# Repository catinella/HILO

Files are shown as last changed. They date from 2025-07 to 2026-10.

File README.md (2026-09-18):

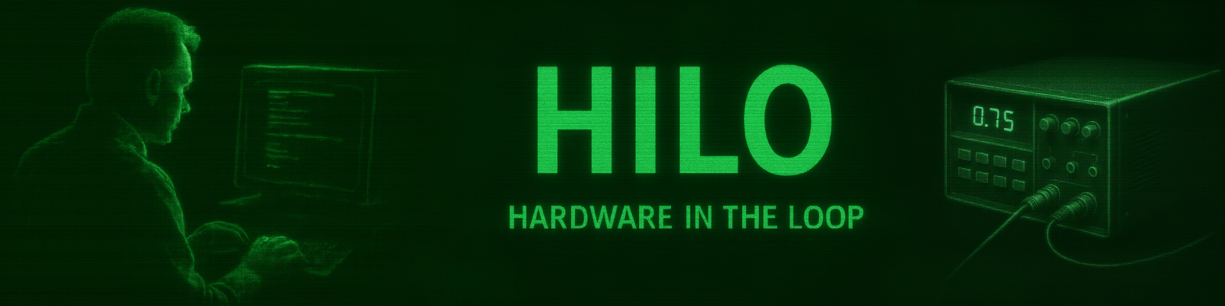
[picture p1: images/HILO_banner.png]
Project's banner


## 1.0 Files

|  Files/Dirs  | Description |
|---|---|
| firmware | The firmware for manager MCU |
| PCB | All the PCBs used in the project |
| console | The software used to manage the HILO  |
| images | Images and diagrams used by README.md |
| lgpl-3.0.txt | L-GPL ver 3.0 license document |

## 2.0 Decription
The goal of this project is to get a device that allows the user to test an electronic system in an easy way, also remotely.
In the 1990 when I was studying at high scool, who was developing new devices, used generic boxes with buttons, switches,
LEDs, displays.... installed on it. This device allowed him to emulate the external environment.

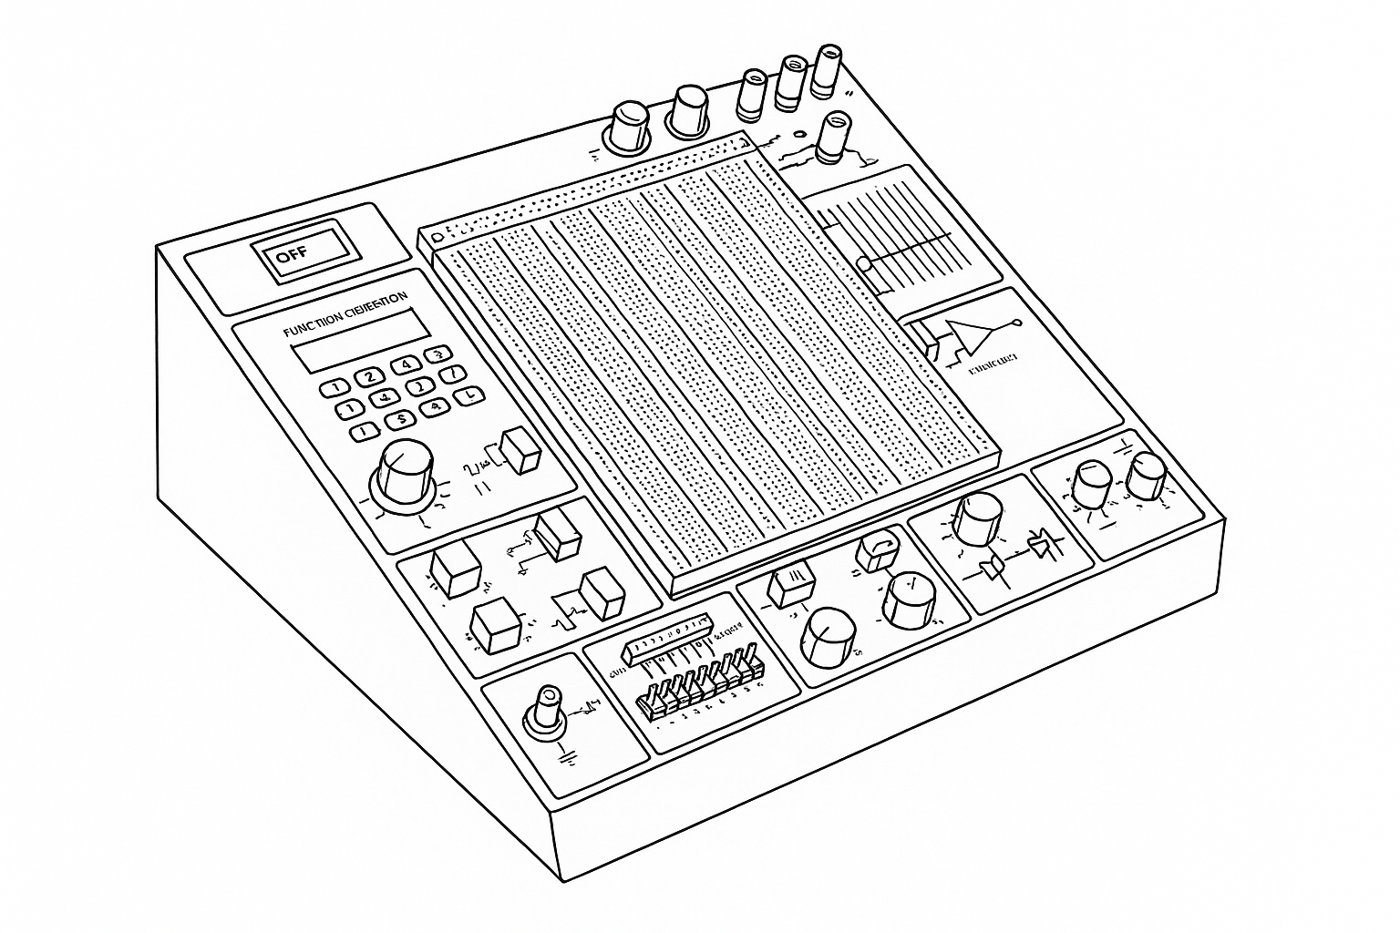
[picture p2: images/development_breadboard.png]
Testing device


It could look like useful for hobbyist, but it is an expensive, big, uncomfortable device, usually. 
For professional using it is not an adequate solution, because td does not allow you to see what happens in very short
time slots. For example, you need to monitor a 8bit bus behaviour after one millisecond after some digital input signal.
In this case, this kind of devices is absolutely unuseful.
Unfortunately, many Italian companies still use the same deplorable methodology, today too! Their test plans do not respect
the [V-model](https://www.sei.cmu.edu/blog/using-v-models-for-testing), and their firmware developers have to work on-site
only.

But the smarter companies use advanced and complicated devices that allow them to test their electronic products remotely,
in deeper and easier way. These tools are very sophisticated and programmable simulator, where they can simulate the
external environment in realistic and reliable way. These tools' class is called 
[**HILO**](https://en.wikipedia.org/wiki/Hardware-in-the-loop_simulation) (Hardware In the LOop).

This project aims to provide a low-cost and very very simple HILO. This one offers less and more limited features,
obviously.
	
#### 2.1 Test mode vs interactive mode
This HILO has two operating modes, that the user can set using the tester client GUI. In the first one (test-mode), the
user can monitor the DUT behavior for output-pins activities that run fast or for a short time periods. In the second one
the user can change the HILO's output-pins, directly, and verifies the DUT's behavior as consequence.

- **Test mode:**
	the user has to create a DUT test-recepit where he has to define the HILO's output-pins values, when they change during
	the test, and the max frequency of the changes. This synchronization will be also used to read the HILO's input-pins.
	Before to start the test, the HILO will convert the pin-status changes definitions in a scheduled output data sequence.
	When this raw-data sequence is ready, a bit configuration will be sent to the output-pins on every chock pulse, and
	the input pins will be read.

- **Interactive mode:**
	In this mode, the user will be able to change the HILO's output-pins values and check for the input ones status, 
	interactively. It is a good way to get an overview on the DUT's behavior, but, because you cannot schedule the
	changes with a precise time, it is not adequate for real-time interactions.

#### 2.3 Communication channel
In order to get a very fast, relayable, and flexible communication channel between the test-client software and the HILO's interface,
TCP/IP limk has been selected. In fact, it allows a huge transfer rate, a very high quality error checking and retransmission, and
virtually-infinite distances. It allows the test operator to work remotely respect to the HILO device, and the DUT, bviousely.
In order to make the HILO device using as comfotable as possible, WiFI connection has been selected. In this way the test operator
can set its own test-desk without to take care of boring cables to connect to it.

#### 2.4 Functional scheme overview:

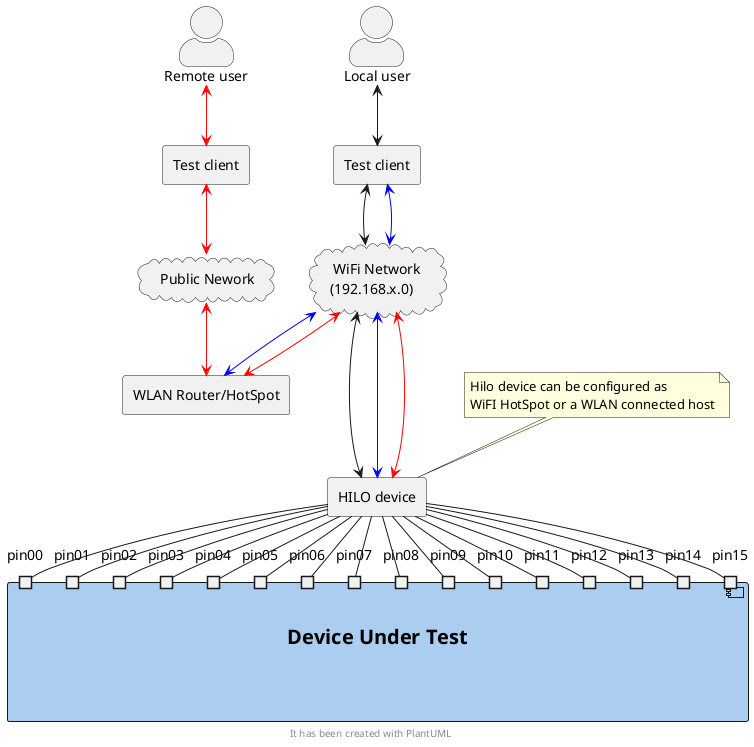
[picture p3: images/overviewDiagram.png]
overview_diagram
 

#### 2.5 Licence:
This project is a free software; you can redistribute it and/or modify it under the terms	of the GNU Lesser General Public License
as published by the Free Software Foundation; either version 3.0 of the License, or (at your option) any later version. 

For further details please read the full [LGPL text file](https://www.gnu.org/licenses/lgpl-3.0.txt).
You should find a copy of the GNU General Public License document in the root folder of the project; if not, write to the 

	Free Software Foundation, Inc.,
	59 Temple Place, Suite 330,
	Boston, MA  02111-1307  USA

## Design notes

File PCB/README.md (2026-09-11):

Project's banner

## 1.0 Files

| Files/Dirs | Description |
|---|---|
| kicadCustomComponents | The KiCAD libraries for the customized symbols/footprints |
| IOlinesManagement | The digital I/O lines interface |
| ElectricProtections | I/O Interface electric protection devices |
| MasterControlUnit | The HILO's brain |

## 2.0 Decription
By the hardware points of view, this HILO is composed by the following separated modules. Everyone of them is connected to
the master one using pin-headers connectors and flat-cables.

- The Master Conroller unit interface the I/O lines with the PC and perform the configured tests
- Digital I/O lines interface
- Output lines electrical protection
- (optional) Dedicated to the Analog lines PCB

## 2.1 Components documentation:
- [APS6404L-3SQR-SN](https://eu.mouser.com/datasheet/3/4815/1/APM_PSRAM_E3_QSPI%20(APS6404L-SQH%20KGD_PKG)%20v4.1.pdf)
- [ESP32 WROOM-32-UE](https://www.espressif.com/sites/default/files/documentation/esp32-wroom-32e_esp32-wroom-32ue_datasheet_en.pdf)
- [ESP32-DevKitC-V4](https://docs.espressif.com/projects/esp-idf/en/release-v4.2/esp32/hw-reference/esp32/get-started-devkitc.html)
- [STM32F407VG](https://www.st.com/resource/en/datasheet/dm00037051.pdf)
- [STM32F407G-DISC1](https://www.st.com/resource/en/data_brief/stm32f4discovery.pdf)

## 2.2 Logic scheme:
Overview Scheme

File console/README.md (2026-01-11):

Project's banner

## 1.0 Files

| Files/Dirs | Description |
|---|---|
| build.pro | QMake rules to build the whole project files |
| [conf.pri] | Building process configuration file |
| envVarOverriding.pri | QMake tool to get config data fron environment vars |
| gdbToConfig.pri | Qmake tool to set debug mode flags |
| utils.pri | QMake general purpose functions library |
| inputDevs | Virtual input devices (DUT point of view) |
| mainApp | The graphic console application |
| outputDevs | Virtual output devices |
| sharedComps | Graphic components used by the other modules |

## 2.0 Description
This folder hosts the HILO's GUI. When you use this HILO in interactive mode, this graphical interface will allow you to set your
test environment with many virtual tools (buttons, led-stripes, switches, keypads, displays... and so on) and verify the DUT's
behavior controlling its input and output in all configurations you have planned.

### 2.1 QT
In order to provide a multiplatform and very flexible GUI I have developed this module using the QT framework. In fact, QT allows
me to modify and create new widgets in a very powerful way.

## 3.0 code building
To provide a multiplaform building chain, I have used the official QT's tool **QMake6**. It requires a configuration file
file.pro) to produce the platform dependent build-chain files (eg. Makefile for Unix/Linux). After you obtained those files , you
can compile the code with your usual tool-chain, directly. For example, to performs the described tasks together, if you are using
a POSIX systems, you can run the following command:

	qmake6 *.pro && make all

[!] Use this approach for all sub-modules' tests too.

## 4.0 How to write new I/O virtual devices

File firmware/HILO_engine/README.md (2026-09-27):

Project's banner

## 1.0 Files

| **Files and dirs** | **Description** |
|---|---|
| build |  The rules you need to compile the project |
| Core |  The project's source code |
| Drivers |  The drivers's source code |
| HILO_engine.ioc | |
| STM32F031K6TX_FLASH.ld |  The linker script generated by CubeMX |

## 2.0 Description

This component is the one that performs the test, effectively.
Please, read the ../README and ../HILO_interface/README files

### 2.1 Firmware's main steps

0) Hardware initialization
   Subsystems initialization and I2C channel opening in slave-mode
		
1) MCU waiting for a command by the HILO_interface component

2) Scheduled test
   if **HENG_TEST_START** command is received and the test has been previously properly configured, then the MCU starts
   to perform the test and stores the results in the SRAM. While this process is running, the MCU can reply to the
   **HENG_TEST_GETSTATUS** request, sending the number of the last executed step. At the end of the test or if an 
   **HENG_TEST_STOP** message is received, the MCU returns to wait for new commands.
		
3) Interactive test
   Before to perform the test, the MCU has to get an **HENG_RT_SETPINSDIR** message to configure the I/O type of its pins.
   When the **HENG_RT_START** command is received, the MCU reads data from its input pins and returns the data to the
   Hilo_interfaces via SPI.
   The user will be able to change the output pins' values with the **HENG_RT_SETPINSVAL** command, in "realtime".
   The **HENG_RT_STOP** command will force the MCU to returns at the initial state.

### 2.2 SRAM

This external memory is used just in the scheduled-test mode. 
In order to achieve better speed performance, the MCU uses two different memory areas, one just for reading operations the other
just for data writing, and they are also connected with two different SPI ports.
For every test's step, MCU will perform the following steps:

1) The output pins configuration will be read from the first memory area
2) HILO's pins will be set properly
3) The HILO's input pins value will be stored in the second memory area.
4) The internal counter will be incremented

Output-pins' configurations layout
		
| Test step | Bits mask (0=IN)  | OUT pins value  |
|---|---|---|
| **step 1**| XXXXXXXX:XXXXXXXX | XXXXXXXX:XXXXXXXX |
| **step 2**| XXXXXXXX:XXXXXXXX | XXXXXXXX:XXXXXXXX |
| **step 3**| XXXXXXXX:XXXXXXXX | XXXXXXXX:XXXXXXXX |
| **step n**|///////////////////|///////////////////|

Test results (8 Bytes) record: digital and analog input-pins values

| Test step  | Inputs pins | Fuses status | Data from A/D |  Not used  |
|---|---|---|---|---|
| **step 0** | 2 bytes | 2 bytes | 2 Bytes |  2 bytes |
| **step 1** | 2 bytes | 2 bytes | 2 Bytes |  2 bytes |
| **step 2** | 2 bytes | 2 bytes | 2 Bytes |  2 bytes |
| **step n** |/////////////|//////////////|///////////////|////////////|

### 2.3 Dynamic I/O configuration

Each test step is encoded using 4 bytes:

- 2 bytes define the I/O direction of the test lines;
- 2 bytes define the values to be generated on the lines configured as outputs.

At first sight, storing the I/O direction for every test step may appear redundant, since in many tests the pin direction does
not change during the whole test sequence.

However, keeping the I/O configuration as part of each test step allows HILO to change the direction of any test line during
test execution. This is required to reproduce the behaviour of bidirectional and half-duplex interfaces.

A particularly relevant example is an open-drain line. In this case, HILO can generate the two logical line states as:

- **LOW:** configure the line as output and drive it low;
- **RELEASED:** configure the line as input, leaving the external pull-up free to drive it high.

Therefore, the I/O direction is not merely a static hardware configuration: it can be considered part of the test stimulus itself.

This flexibility has a cost, since the STM32F407 must potentially update the GPIO configuration at every test step. However, the
target test frequency is in the range of a few hundred kHz. At 500 kHz, for example, a complete test step lasts 2 µs, corresponding
to 336 CPU cycles with the STM32F407 running at 168 MHz.

The worst-case execution time of a test step must therefore satisfy:

`Tstep = TSRAM_read + TGPIO_config + TGPIO_write + TGPIO_read + TSRAM_write + Toverhead < Ttimer`

The actual execution time will be measured during implementation. If the complete operation fits within the required timer period with
sufficient margin, the additional per-step I/O configuration is considered an acceptable cost for the flexibility it provides.

## 3.0 Building procedure
	In order to keep track of every change, in the building rules too, I have chosen to use the usual Makefile building chain
	instead the ST proprietary one. So, in order to build the firmware use make command from the "build" folder inside

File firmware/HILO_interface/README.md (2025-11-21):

Project's banner

## 1.0 Files

| **Files and dirs** | **Description** |
|---|---|
| CMakeLists.txt | It contains the rules you need to build the firmware or the integration tests |
| components | All used by firmware libraries are stored in a sub-folder of this one |
| main | It contains the firmware and integration tests |
| [build] | Temporary folder used to buid the code |
| [CMakeLists.conf]  | Building process' configuration file |
| configUtils.cmake  | CMake functions library |
| sdkconfig | The ESP-IDF's configuration file |

## 2.0 Description
This component provides the HILO device's interface feature. As you can read in the diagram in the main README file, this interface
is used by the test client software, and accepts data/commands to configure, start, manage the test process.

### 2.1 Hardware considerations
The MCU used to implement the HILO's interface is the 
[ESP32 WROOM-32-UE](https://www.espressif.com/sites/default/files/documentation/esp32-wroom-32e_esp32-wroom-32ue_datasheet_en.pdf).
It is a cheap device but its characteristics allows it to perform all the required features, easily. The followings are the main
ones:
- 448 KB ROM
- 520 KB SRAM
- WiFI support (802.11 b/g/n (802.11n up to 150 Mbps))
- Integrated crystal (40MHz)
- External antennna
- SPI and I2c BUS support

#### 2.2 Communication protocol
in order to obtain the most standard communication protocol possible, which also implements sophisticated access protection
mechanisms, the REST API protocol has been used for all HILO device's external communication.
	
###### 2.2.1 REST APIs for scheduled-test mode:
| REST API |  Description |
|---|---|
| **POST** <HILO>/test/set_recepit  | The test's recipit will be accepted, converted, and stored in the SRAM |
| **POST** <HILO>/test/start | If a recepit has been accepted and converted then this command will start the test |
| **POST** <HILO>/test/stop | If a test is running then it will be stopped |
| **GET**  <HILO>/test/get_status | It returns the test status {IN_PROGRESS|COMPLETED|STOOPED} |
| **GET**  <HILO>/test/get_resuts | It returns all data produced by the last executed test |

###### 2.2.2 JSONs for scheduled-test mode:
	<HILO>/test/set_recepit = {
		configuration: {
			//
			// I/O direction configuration
			//
			pin0:  {IN|OUT}, 
			pin1:  {IN|OUT},
			...
			pin15: {IN|OUT},

			// Frequency in Khz
			freq:  <n>           // 1 = 0.1 Khz
		},
		test_outputData[] : {
			type:  fixedTimePeriod,
			pin:   <0-15>,
			value: {high|low|swap},
			start: <milliseconds>,
			stop:  <milliseconds>
		}, {
			type:      squareWave,
			pin:       <0-15>,
			period:    <milliseconds>,
			dutyCycle: <0-100>,          // percent
			start:     <milliseconds>,
			stop:      <milliseconds>
		}, {
			type:   number,
			pins[]: <0-15>, <0-15>, <0-15>, <0-15>, <0-15>, <0-15>, <0-15>, <0-15>  // 8bits MSB --> LSB
			period: <milliseconds>,
			start:  <milliseconds>,
			stop:   <milliseconds>
		}, ...
	}

###### 2.2.3 REST APIs for interactive test mode:
| REST API |  Description |
|---|---|
| **POST** <HILO>/intv/configure | It configures the bits direction ant the TCL's ip-address|
| **POST** <HILO>/intv/send_data | It force the HILO's output pins to change their status |
| **GET**  <HILO>/intv/get_fuses | It returns the status of the fuses |

###### 2.2.4 JSONs for interactive-test mode:
	<HILO>/intv/configure = {
		pindir = <16bit hex-number>   // 0 = input; 1 = output
		streamaddr = <test-client ip-addr:socket>
	}
	<HILO>/intv/send_data = <16bit hex-number>

#### 2.3 SRAM content
The SRAMs are used just in scheduled-test-mode. This modality is based on a test-recipit composed by all the I/O changes and
the time of their performing, mainly. This data is translated by the HILO-interface into an IO-pins configurations sequence,
one for every time time period. Then the sequence is written into one of the two SRAM banks.

#### 2.4 Communication with HILO-engine
In order to exchange adata between the interface and the engine, they uses two different communication data buses. The first one
is used by the interface to send commands, and because it does not need to be very fast, the 12C bus has been selected for this
purpose. The second bus is used by the engine's MCU to send the input-pins data to the interface, and to allow fast data
transmission rating, the SPI bus has been selected.

###### 2.4.1 HILO-engine accepted commands in scheduled-test mode:

| **8bit numeric ID** | **Descriprion** |
|---|---|
| HENG_TEST_START | bla bla bla |
| HENG_TEST_STOP | bla bla bla |
| HENG_TEST_GETSTATUS | bla bla bla |
		 
###### 2.4.2 HILO-engine accepted commands in interactive mode:

|  **8bit numeric ID**  | **Data field** |  **Descriprion** |
|---|---|---|
| HENG_INTV_START | N/A | |
| HENG_INTV_STOP | N/A | |
| HENG_INTV_SETPINSDIR  |  \<pins-dir> | |
| HENG_INTV_SETPINSVAL  | \<pins-value>  | |

## 3.0 Buiding procedure
In order to build the code for ESP32 that belongs to this module, you need the
[ESP-IDS (5.4.x)](https://docs.espressif.com/projects/esp-idf/en/v5.4.2/esp32/get-started/index.html.) software framework.
Please, read the documentation to get the right procedure to build the code.

This firmware source code tree contains unit-tests and integration tests too. The **unit-tests** cover the components' code, not the
main. To build these tests find the "test" folder into the proper component home (component/\<component-name>) and follow the
instructions decribed in the README or Makefile file storeed in tht path. 
To execute the **integration tests**, you need to build the test for the target and also upload the test-firmware into the target. So,
in order to select wich firmware (test<n>.c, ...prod.c) you want to use you have to set the Makefike.conf file properly.
For further information, please, read the documentation section in the CMakeLists.txt file.

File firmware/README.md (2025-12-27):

Project's banner

## 1.0 Files

| **Files and dirs** | **Description** |
|---|---|
| HILO_engine | The real-time component that performs the scheduled test |
| HILO_interface | The component that interface the HILO's engine with the test client system |

## 2.0 Description
In oder to get a more comfortable and an high performave instrument, the HILO device uses more MCUs.
This folder contains the firmwares for all used MCUs.
	
### 2.1 Dataflow description:
Please, consider the logic scheme stored in the ../PCB/README file.
The HILO can function in two different ways: **scheduled-mode** and **interactive-mode**.

- In the first one, the user have to prepare a test's recipit and send it via REST API to the HILO_interface component.
Then it will instructs the HILO_engine on the step iw will have to follow to perform the test correctly. At the end of
the test, the software-client will retrive all resulted data, and the user will be able to evaluate the the DUT's
behaviohr.
	
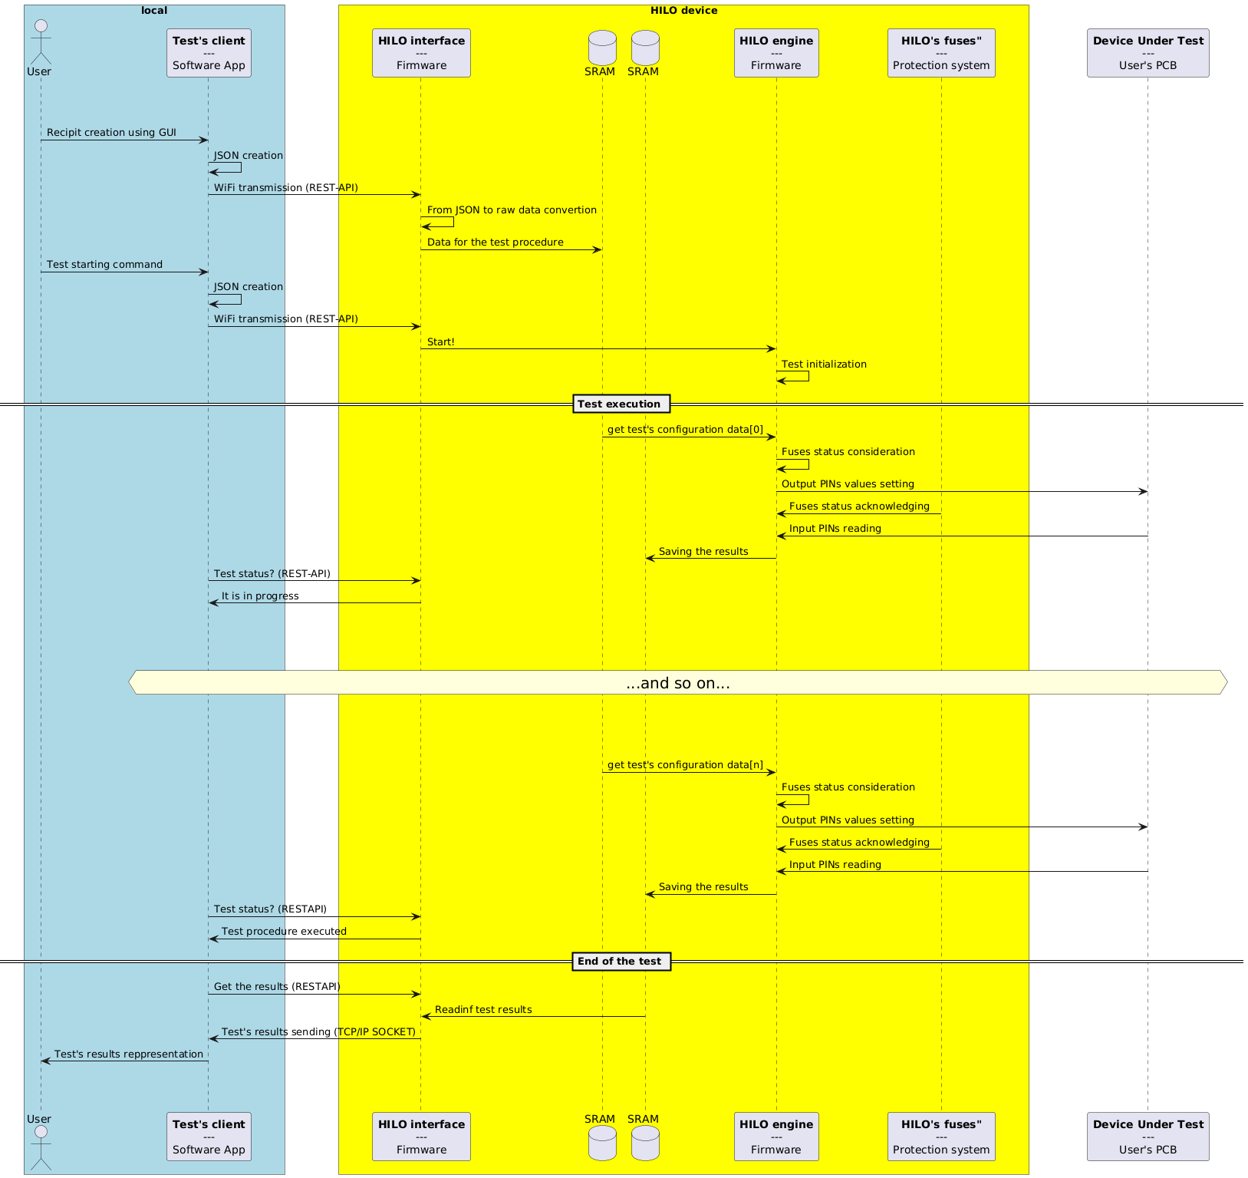
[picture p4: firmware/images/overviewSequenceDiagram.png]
Time sequence diagram for the **scheduled mode**


- In the interactive-mode, the user can change the output-pins value via REST API, dinamically. All data on the monitored
input pins will be continuously reported via TCP/IP stream. So, the user will be able to evaluate the DUT behavior
modifying the DUT's input and checking for the DUT's output, dinamically. Because the DUT's inputs change manually, the
HILO's sample rating is set to 1Khz.

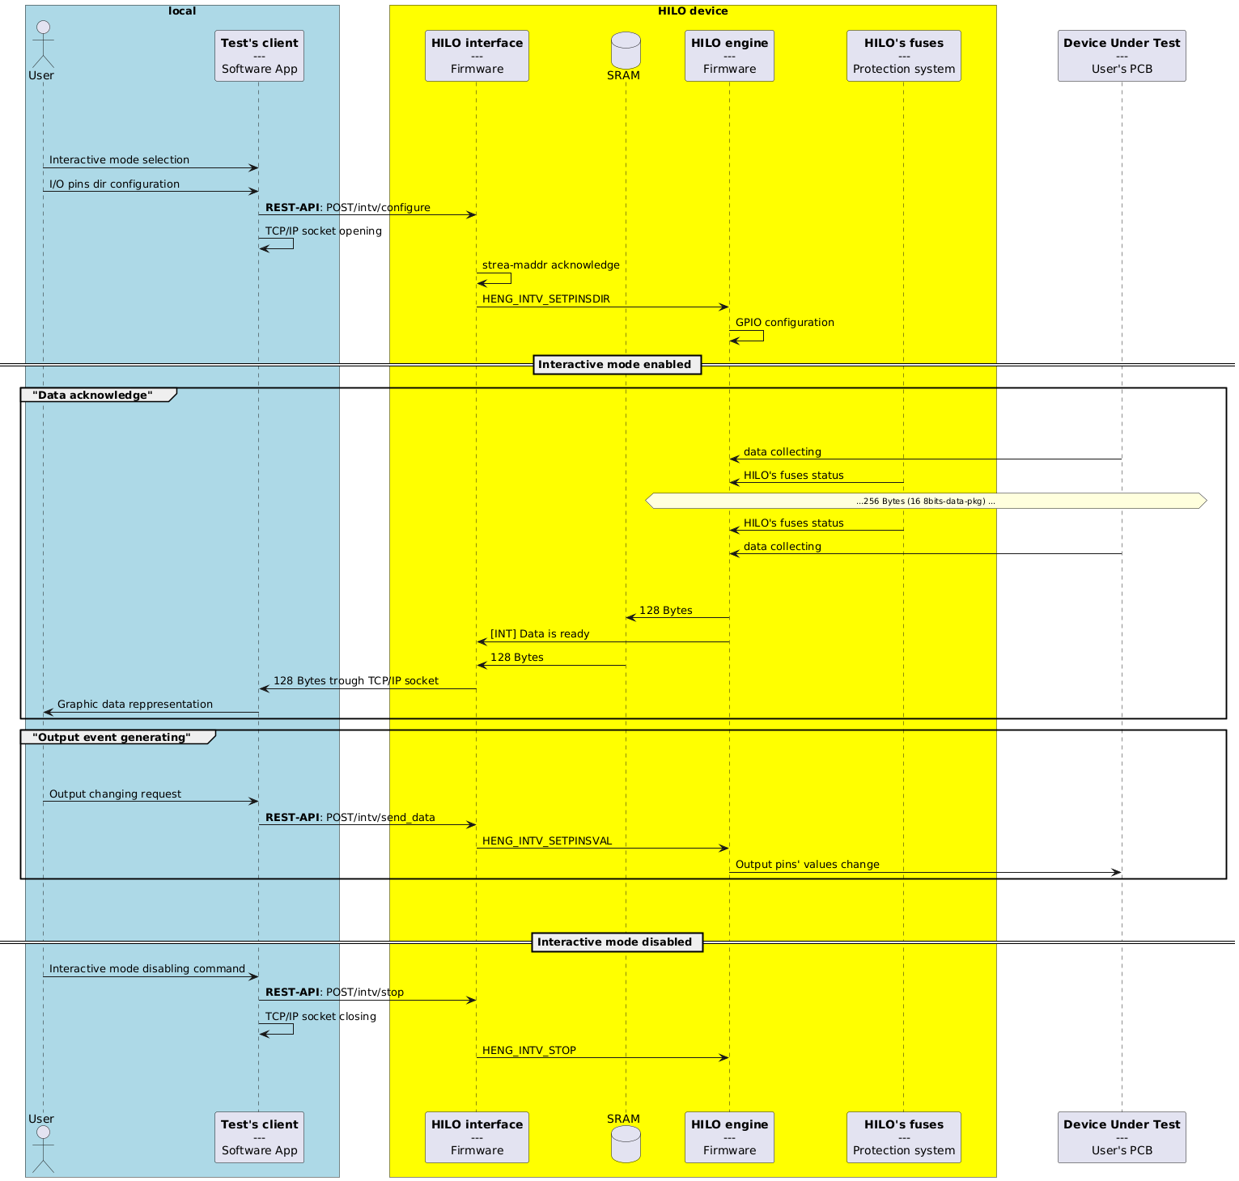
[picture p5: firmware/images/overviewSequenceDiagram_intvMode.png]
Time sequence diagram for the **interactive mode**


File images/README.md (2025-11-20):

Project's banner

## 1.0 Files

| Files and Directories | Description |
|---|---|
|development_breadboard.png | Image used in the main README.md file |
|HILO_banner.png | The title of every README.md file |
|Makefile | Automation tool for diagram generating  |
|[Makefile.conf] | Optional Makefile's configuration file  |
|overviewDiagram.puml | Diagram used in the main README.md file |
|overviewDiagram.png | Generated image |

## 2.0 Decription
In order to provide README files where they are more comfortable to read, I choice to use Markup-Down (MD) language instead row
ASCII text. This type of README files are more compatible with GITHUB and the MD language has become an appreciated standart for
the documentation files. 

One of the more appreciated MD's feature is the possibility to embedd images, diagrams, links... into the document. But in order
to keepm an ordered tree, I choise to store all images in this folder.

## 2.1 Diagram generating
In order to include the diagram's file in the project's file versioning I use the [plantuml](https://plantuml.com) app. It allows
me to create complicated graphic diagrams starting by a sequence of ASCII instructions. The 
[offical manual](https://plantuml.com/guide#goog_rewarded) is also available.

## 2.2 Images on GIT??!!!??
I know, many people are drawing a terrible expressions in their face, now! GIT is not made to store images. I completely
agree with you. My solution would be to include puml file only in git, and store all static images in a web-area. Unfortunately
GITHB does not provide a web-space!! Someone use a proper branch for the image files. But it looks like Walt Disney's catoon
Pippo (Goofy in EN) when he sweep the dust under the carpet, IMHO. So, I have to wait that GitHUB implements a PlantUML engine in
its Markdown language interpreter.

However, I will be happy to evaluate every possible suggestion

A sentence by ChatGPT-5.1 about PlantUML: "___Il futuro si sta allineando a PlantUML, non il contrario.___"; translated version
"___So the future is aligning with PlantUML, not the other way around.___"
by ChatGPT (20/11/2025)

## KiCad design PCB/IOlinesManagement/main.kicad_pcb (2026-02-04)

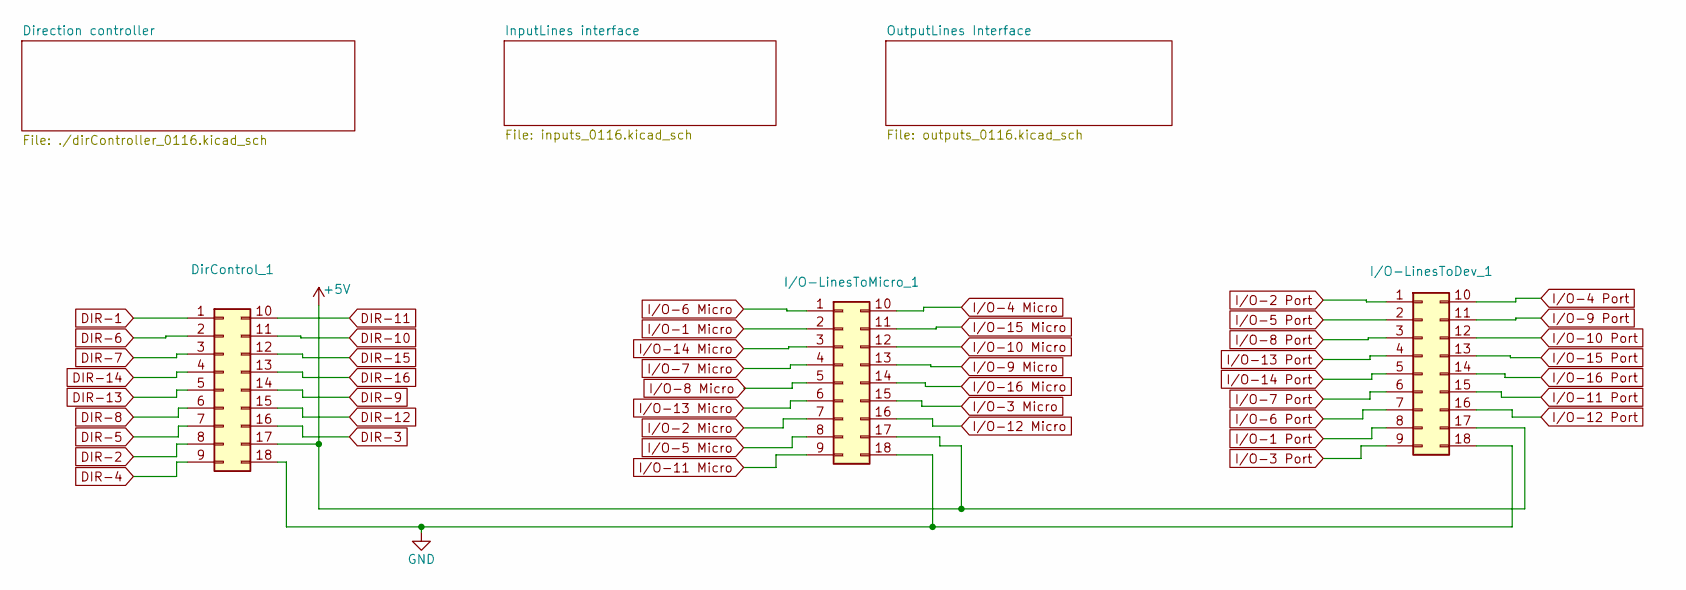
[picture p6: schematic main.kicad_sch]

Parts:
DirControl_1: Conn_02x09_Top_Bottom; PinHeader_2x09_P2.54mm_Vertical
I/O-LinesToDev_1: Conn_02x09_Top_Bottom; PinHeader_2x09_P2.54mm_Vertical
I/O-LinesToMicro_1: Conn_02x09_Top_Bottom; PinHeader_2x09_P2.54mm_Vertical

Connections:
+5V: DirControl_1.17, I/O-LinesToDev_1.17, I/O-LinesToMicro_1.17; also elsewhere on the board
DIR-1: DirControl_1.1; also elsewhere on the board
DIR-2: DirControl_1.8; also elsewhere on the board
DIR-3: DirControl_1.16; also elsewhere on the board
DIR-4: DirControl_1.9; also elsewhere on the board
DIR-5: DirControl_1.7; also elsewhere on the board
DIR-6: DirControl_1.2; also elsewhere on the board
DIR-7: DirControl_1.3; also elsewhere on the board
DIR-8: DirControl_1.6; also elsewhere on the board
DIR-9: DirControl_1.14; also elsewhere on the board
DIR-10: DirControl_1.11; also elsewhere on the board
DIR-11: DirControl_1.10; also elsewhere on the board
DIR-12: DirControl_1.15; also elsewhere on the board
DIR-13: DirControl_1.5; also elsewhere on the board
DIR-14: DirControl_1.4; also elsewhere on the board
DIR-15: DirControl_1.12; also elsewhere on the board
DIR-16: DirControl_1.13; also elsewhere on the board
GND: DirControl_1.18, I/O-LinesToDev_1.18, I/O-LinesToMicro_1.18; also elsewhere on the board
I/O-1 Micro: I/O-LinesToMicro_1.2; also elsewhere on the board
I/O-1 Port: I/O-LinesToDev_1.8; also elsewhere on the board
I/O-2 Micro: I/O-LinesToMicro_1.7; also elsewhere on the board
I/O-2 Port: I/O-LinesToDev_1.1; also elsewhere on the board
I/O-3 Micro: I/O-LinesToMicro_1.15; also elsewhere on the board
I/O-3 Port: I/O-LinesToDev_1.9; also elsewhere on the board
I/O-4 Micro: I/O-LinesToMicro_1.10; also elsewhere on the board
I/O-4 Port: I/O-LinesToDev_1.10; also elsewhere on the board
I/O-5 Micro: I/O-LinesToMicro_1.8; also elsewhere on the board
I/O-5 Port: I/O-LinesToDev_1.2; also elsewhere on the board
I/O-6 Micro: I/O-LinesToMicro_1.1; also elsewhere on the board
I/O-6 Port: I/O-LinesToDev_1.7; also elsewhere on the board
I/O-7 Micro: I/O-LinesToMicro_1.4; also elsewhere on the board
I/O-7 Port: I/O-LinesToDev_1.6; also elsewhere on the board
I/O-8 Micro: I/O-LinesToMicro_1.5; also elsewhere on the board
I/O-8 Port: I/O-LinesToDev_1.3; also elsewhere on the board
I/O-9 Micro: I/O-LinesToMicro_1.13; also elsewhere on the board
I/O-9 Port: I/O-LinesToDev_1.11; also elsewhere on the board
I/O-10 Micro: I/O-LinesToMicro_1.12; also elsewhere on the board
I/O-10 Port: I/O-LinesToDev_1.12; also elsewhere on the board
I/O-11 Micro: I/O-LinesToMicro_1.9; also elsewhere on the board
I/O-11 Port: I/O-LinesToDev_1.15; also elsewhere on the board
I/O-12 Micro: I/O-LinesToMicro_1.16; also elsewhere on the board
I/O-12 Port: I/O-LinesToDev_1.16; also elsewhere on the board
I/O-13 Micro: I/O-LinesToMicro_1.6; also elsewhere on the board
I/O-13 Port: I/O-LinesToDev_1.4; also elsewhere on the board
I/O-14 Micro: I/O-LinesToMicro_1.3; also elsewhere on the board
I/O-14 Port: I/O-LinesToDev_1.5; also elsewhere on the board
I/O-15 Micro: I/O-LinesToMicro_1.11; also elsewhere on the board
I/O-15 Port: I/O-LinesToDev_1.13; also elsewhere on the board
I/O-16 Micro: I/O-LinesToMicro_1.14; also elsewhere on the board
I/O-16 Port: I/O-LinesToDev_1.14; also elsewhere on the board

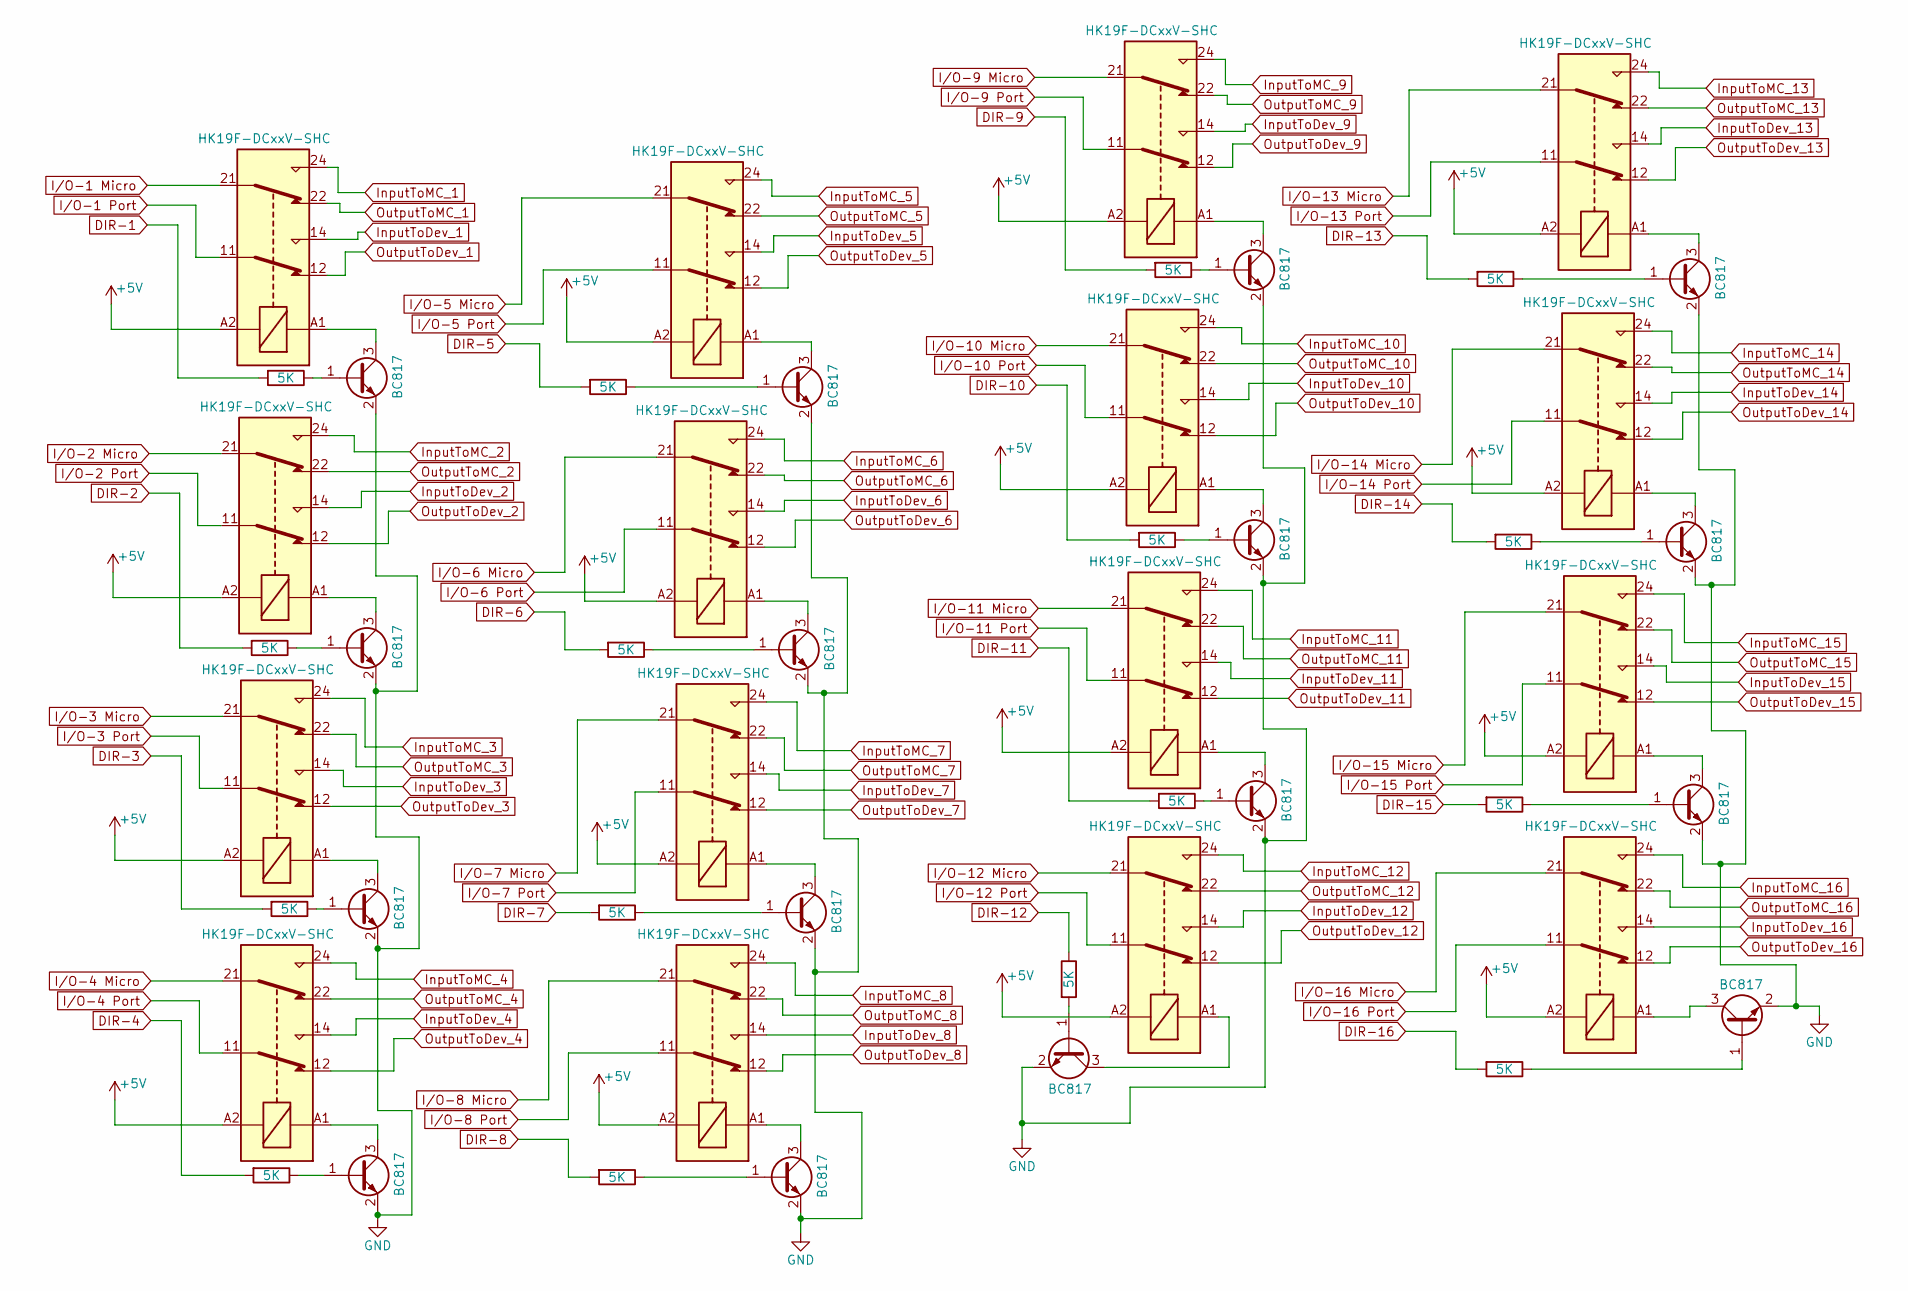
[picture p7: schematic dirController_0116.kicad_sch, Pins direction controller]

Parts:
K1, K2, K3, K4, K5, K6, K7, K8, K9, K10, K11, K12, K13, K14, K15, K16: HK19F-DCxxV-SHC; Relay_DPDT_Finder_30.22
Q1, Q2, Q3, Q4, Q5, Q6, Q7, Q8, Q9, Q10, Q11, Q12, Q13, Q14, Q15, Q16: BC817; SOT-23
R1, R2, R3, R4, R5, R6, R7, R8, R9, R10, R11, R12, R13, R14, R15, R16: 5K; R_1206_3216Metric

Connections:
+5V: K1.A2, K2.A2, K3.A2, K4.A2, K5.A2, K6.A2, K7.A2, K8.A2, K9.A2, K10.A2, K11.A2, K12.A2, K13.A2, K14.A2, K15.A2, K16.A2; also elsewhere on the board
DIR-1: R3.2; also elsewhere on the board
DIR-2: R1.2; also elsewhere on the board
DIR-3: R4.2; also elsewhere on the board
DIR-4: R2.2; also elsewhere on the board
DIR-5: R5.2; also elsewhere on the board
DIR-6: R8.2; also elsewhere on the board
DIR-7: R6.2; also elsewhere on the board
DIR-8: R7.2; also elsewhere on the board
DIR-9: R11.2; also elsewhere on the board
DIR-10: R10.2; also elsewhere on the board
DIR-11: R12.2; also elsewhere on the board
DIR-12: R9.1; also elsewhere on the board
DIR-13: R13.2; also elsewhere on the board
DIR-14: R16.2; also elsewhere on the board
DIR-15: R14.2; also elsewhere on the board
DIR-16: R15.2; also elsewhere on the board
GND: Q1.2 (E), Q2.2 (E), Q3.2 (E), Q4.2 (E), Q5.2 (E), Q6.2 (E), Q7.2 (E), Q8.2 (E), Q9.2 (E), Q10.2 (E), Q11.2 (E), Q12.2 (E), Q13.2 (E), Q14.2 (E), Q15.2 (E), Q16.2 (E); also elsewhere on the board
InputToDev_1: K1.14; also elsewhere on the board
InputToDev_2: K2.14; also elsewhere on the board
InputToDev_3: K3.14; also elsewhere on the board
InputToDev_4: K4.14; also elsewhere on the board
InputToDev_5: K5.14; also elsewhere on the board
InputToDev_6: K6.14; also elsewhere on the board
InputToDev_7: K7.14; also elsewhere on the board
InputToDev_8: K8.14; also elsewhere on the board
InputToDev_9: K9.14; also elsewhere on the board
InputToDev_10: K10.14; also elsewhere on the board
InputToDev_11: K11.14; also elsewhere on the board
InputToDev_12: K12.14; also elsewhere on the board
InputToDev_13: K13.14; also elsewhere on the board
InputToDev_14: K14.14; also elsewhere on the board
InputToDev_15: K15.14; also elsewhere on the board
InputToDev_16: K16.14; also elsewhere on the board
InputToMC_1: K1.24; also elsewhere on the board
InputToMC_2: K2.24; also elsewhere on the board
InputToMC_3: K3.24; also elsewhere on the board
InputToMC_4: K4.24; also elsewhere on the board
InputToMC_5: K5.24; also elsewhere on the board
InputToMC_6: K6.24; also elsewhere on the board
InputToMC_7: K7.24; also elsewhere on the board
InputToMC_8: K8.24; also elsewhere on the board
InputToMC_9: K9.24; also elsewhere on the board
InputToMC_10: K10.24; also elsewhere on the board
InputToMC_11: K11.24; also elsewhere on the board
InputToMC_12: K12.24; also elsewhere on the board
InputToMC_13: K13.24; also elsewhere on the board
InputToMC_14: K14.24; also elsewhere on the board
InputToMC_15: K15.24; also elsewhere on the board
InputToMC_16: K16.24; also elsewhere on the board
I/O-1 Micro: K1.21; also elsewhere on the board
I/O-1 Port: K1.11; also elsewhere on the board
I/O-2 Micro: K2.21; also elsewhere on the board
I/O-2 Port: K2.11; also elsewhere on the board
I/O-3 Micro: K3.21; also elsewhere on the board
I/O-3 Port: K3.11; also elsewhere on the board
I/O-4 Micro: K4.21; also elsewhere on the board
I/O-4 Port: K4.11; also elsewhere on the board
I/O-5 Micro: K5.21; also elsewhere on the board
I/O-5 Port: K5.11; also elsewhere on the board
I/O-6 Micro: K6.21; also elsewhere on the board
I/O-6 Port: K6.11; also elsewhere on the board
I/O-7 Micro: K7.21; also elsewhere on the board
I/O-7 Port: K7.11; also elsewhere on the board
I/O-8 Micro: K8.21; also elsewhere on the board
I/O-8 Port: K8.11; also elsewhere on the board
I/O-9 Micro: K9.21; also elsewhere on the board
I/O-9 Port: K9.11; also elsewhere on the board
I/O-10 Micro: K10.21; also elsewhere on the board
I/O-10 Port: K10.11; also elsewhere on the board
I/O-11 Micro: K11.21; also elsewhere on the board
I/O-11 Port: K11.11; also elsewhere on the board
I/O-12 Micro: K12.21; also elsewhere on the board
I/O-12 Port: K12.11; also elsewhere on the board
I/O-13 Micro: K13.21; also elsewhere on the board
I/O-13 Port: K13.11; also elsewhere on the board
I/O-14 Micro: K14.21; also elsewhere on the board
I/O-14 Port: K14.11; also elsewhere on the board
I/O-15 Micro: K15.21; also elsewhere on the board
I/O-15 Port: K15.11; also elsewhere on the board
I/O-16 Micro: K16.21; also elsewhere on the board
I/O-16 Port: K16.11; also elsewhere on the board
unnamed: Q1.1 (B), R3.1
unnamed: K1.A1, Q1.3 (C)
unnamed: Q2.1 (B), R1.1
unnamed: K2.A1, Q2.3 (C)
unnamed: Q3.1 (B), R4.1
unnamed: K3.A1, Q3.3 (C)
unnamed: Q4.1 (B), R2.1
unnamed: K4.A1, Q4.3 (C)
unnamed: Q5.1 (B), R7.1
unnamed: K8.A1, Q5.3 (C)
unnamed: Q6.1 (B), R8.1
unnamed: K6.A1, Q6.3 (C)
unnamed: Q7.1 (B), R5.1
unnamed: K5.A1, Q7.3 (C)
unnamed: Q8.1 (B), R6.1
unnamed: K7.A1, Q8.3 (C)
unnamed: Q9.1 (B), R9.2
unnamed: K12.A1, Q9.3 (C)
unnamed: Q10.1 (B), R11.1
unnamed: K9.A1, Q10.3 (C)
unnamed: Q11.1 (B), R10.1
unnamed: K10.A1, Q11.3 (C)
unnamed: Q12.1 (B), R12.1
unnamed: K11.A1, Q12.3 (C)
unnamed: Q13.1 (B), R16.1
unnamed: K14.A1, Q13.3 (C)
unnamed: Q14.1 (B), R13.1
unnamed: K13.A1, Q14.3 (C)
unnamed: Q15.1 (B), R14.1
unnamed: K15.A1, Q15.3 (C)
unnamed: Q16.1 (B), R15.1
unnamed: K16.A1, Q16.3 (C)
OutputToDev_1: K1.12; also elsewhere on the board
OutputToDev_2: K2.12; also elsewhere on the board
OutputToDev_3: K3.12; also elsewhere on the board
OutputToDev_4: K4.12; also elsewhere on the board
OutputToDev_5: K5.12; also elsewhere on the board
OutputToDev_6: K6.12; also elsewhere on the board
OutputToDev_7: K7.12; also elsewhere on the board
OutputToDev_8: K8.12; also elsewhere on the board
OutputToDev_9: K9.12; also elsewhere on the board
OutputToDev_10: K10.12; also elsewhere on the board
OutputToDev_11: K11.12; also elsewhere on the board
OutputToDev_12: K12.12; also elsewhere on the board
OutputToDev_13: K13.12; also elsewhere on the board
OutputToDev_14: K14.12; also elsewhere on the board
OutputToDev_15: K15.12; also elsewhere on the board
OutputToDev_16: K16.12; also elsewhere on the board
OutputToMC_1: K1.22; also elsewhere on the board
OutputToMC_2: K2.22; also elsewhere on the board
OutputToMC_3: K3.22; also elsewhere on the board
OutputToMC_4: K4.22; also elsewhere on the board
OutputToMC_5: K5.22; also elsewhere on the board
OutputToMC_6: K6.22; also elsewhere on the board
OutputToMC_7: K7.22; also elsewhere on the board
OutputToMC_8: K8.22; also elsewhere on the board
OutputToMC_9: K9.22; also elsewhere on the board
OutputToMC_10: K10.22; also elsewhere on the board
OutputToMC_11: K11.22; also elsewhere on the board
OutputToMC_12: K12.22; also elsewhere on the board
OutputToMC_13: K13.22; also elsewhere on the board
OutputToMC_14: K14.22; also elsewhere on the board
OutputToMC_15: K15.22; also elsewhere on the board
OutputToMC_16: K16.22; also elsewhere on the board

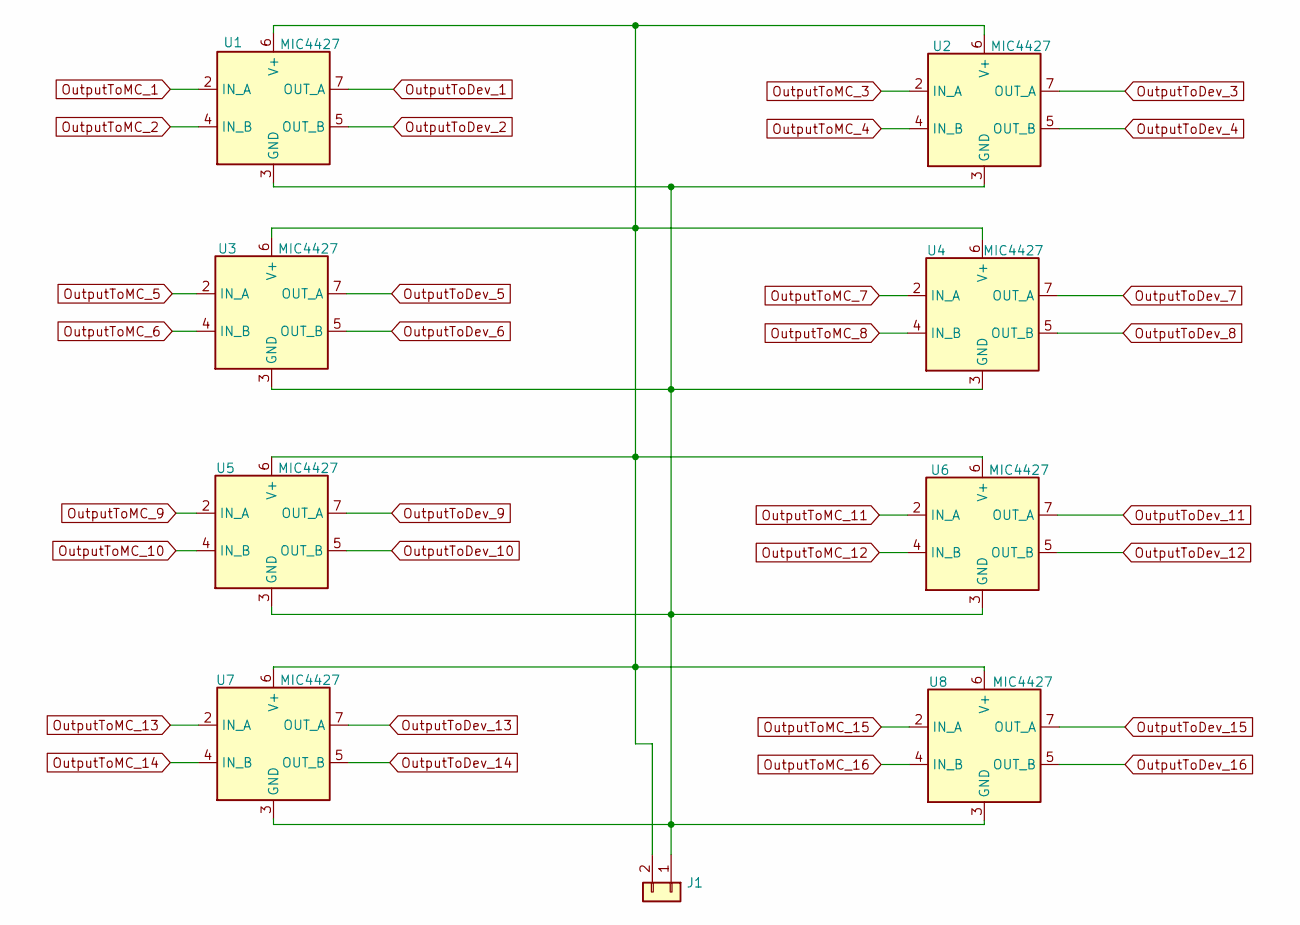
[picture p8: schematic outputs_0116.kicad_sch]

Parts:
J1: Conn_01x02; PinHeader_1x02_P2.54mm_Vertical
U1, U2, U3, U4, U5, U6, U7, U8: MIC4427; MSOP-8_3x3mm_P0.65mm

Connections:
unnamed: J1.1, U1.3 (GND), U2.3 (GND), U3.3 (GND), U4.3 (GND), U5.3 (GND), U6.3 (GND), U7.3 (GND), U8.3 (GND)
unnamed: J1.2, U1.6 (V+), U2.6 (V+), U3.6 (V+), U4.6 (V+), U5.6 (V+), U6.6 (V+), U7.6 (V+), U8.6 (V+)
OutputToDev_1: U1.7 (OUT_A); also elsewhere on the board
OutputToDev_2: U1.5 (OUT_B); also elsewhere on the board
OutputToDev_3: U2.7 (OUT_A); also elsewhere on the board
OutputToDev_4: U2.5 (OUT_B); also elsewhere on the board
OutputToDev_5: U3.7 (OUT_A); also elsewhere on the board
OutputToDev_6: U3.5 (OUT_B); also elsewhere on the board
OutputToDev_7: U4.7 (OUT_A); also elsewhere on the board
OutputToDev_8: U4.5 (OUT_B); also elsewhere on the board
OutputToDev_9: U5.7 (OUT_A); also elsewhere on the board
OutputToDev_10: U5.5 (OUT_B); also elsewhere on the board
OutputToDev_11: U6.7 (OUT_A); also elsewhere on the board
OutputToDev_12: U6.5 (OUT_B); also elsewhere on the board
OutputToDev_13: U7.7 (OUT_A); also elsewhere on the board
OutputToDev_14: U7.5 (OUT_B); also elsewhere on the board
OutputToDev_15: U8.7 (OUT_A); also elsewhere on the board
OutputToDev_16: U8.5 (OUT_B); also elsewhere on the board
OutputToMC_1: U1.2 (IN_A); also elsewhere on the board
OutputToMC_2: U1.4 (IN_B); also elsewhere on the board
OutputToMC_3: U2.2 (IN_A); also elsewhere on the board
OutputToMC_4: U2.4 (IN_B); also elsewhere on the board
OutputToMC_5: U3.2 (IN_A); also elsewhere on the board
OutputToMC_6: U3.4 (IN_B); also elsewhere on the board
OutputToMC_7: U4.2 (IN_A); also elsewhere on the board
OutputToMC_8: U4.4 (IN_B); also elsewhere on the board
OutputToMC_9: U5.2 (IN_A); also elsewhere on the board
OutputToMC_10: U5.4 (IN_B); also elsewhere on the board
OutputToMC_11: U6.2 (IN_A); also elsewhere on the board
OutputToMC_12: U6.4 (IN_B); also elsewhere on the board
OutputToMC_13: U7.2 (IN_A); also elsewhere on the board
OutputToMC_14: U7.4 (IN_B); also elsewhere on the board
OutputToMC_15: U8.2 (IN_A); also elsewhere on the board
OutputToMC_16: U8.4 (IN_B); also elsewhere on the board

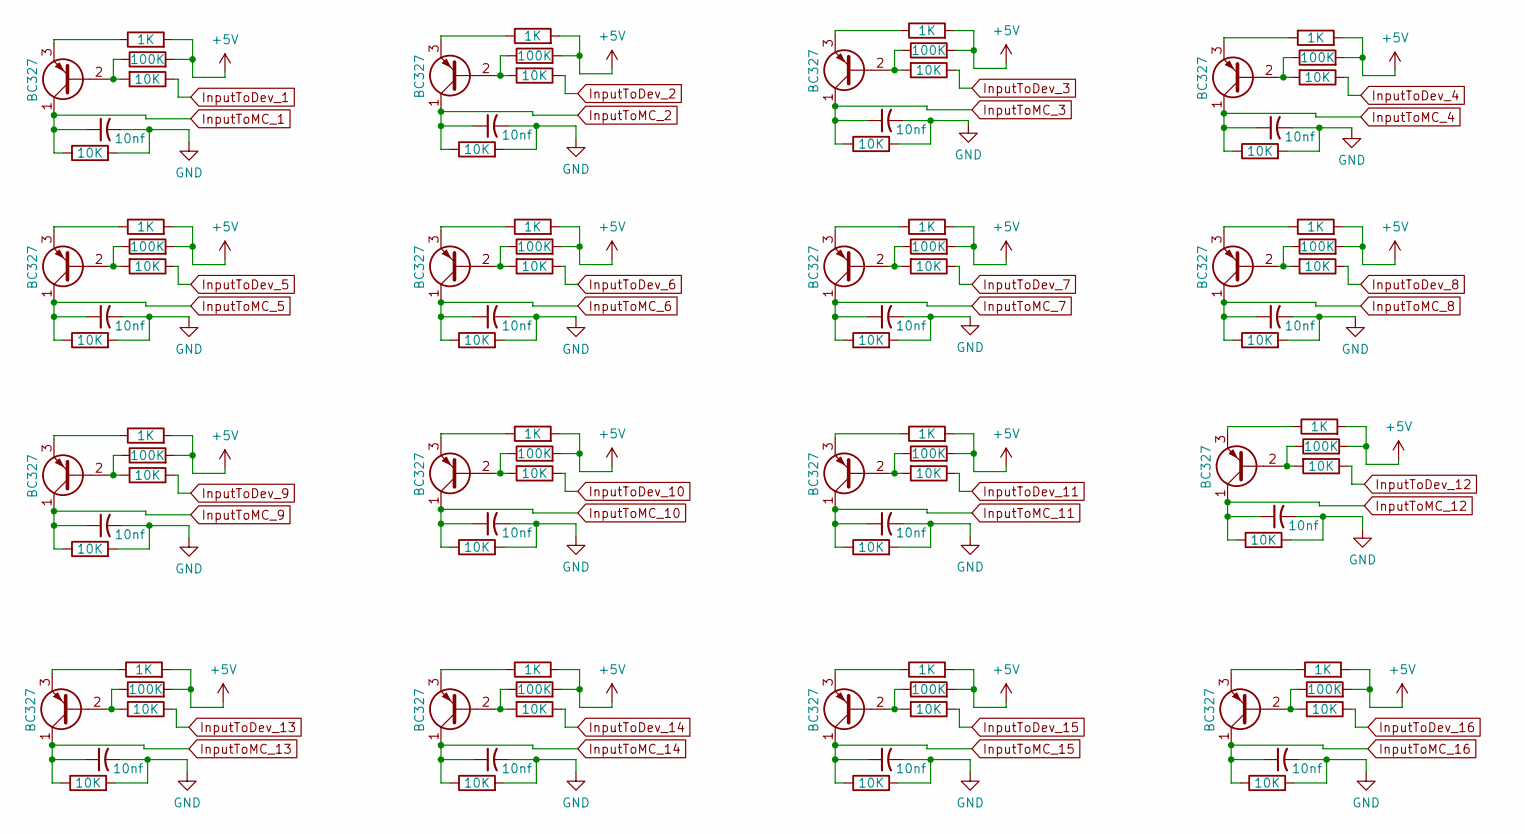
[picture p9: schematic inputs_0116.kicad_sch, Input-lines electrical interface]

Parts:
C1, C2, C3, C4, C5, C6, C7, C8, C9, C10, C11, C12, C13, C14, C15, C16: 10nf; C_Disc_D4.3mm_W1.9mm_P5.00mm
Q25, Q34, Q51, Q52, Q53, Q54, Q55, Q56, Q57, Q58, Q59, Q60, Q61, Q62, Q63, Q64: BC327; TO-92_Inline_Wide
R17, R54, R82, R112, R113, R114, R117, R120, R125, R128, R140, R146, R147, R148, R151, R156: 1K; R_1206_3216Metric
R40, R56, R65, R84, R105, R106, R107, R108, R109, R110, R111, R116, R119, R122, R124, R127, R130, R132, R133, R134, R135, R136, R137, R138, R139, R142, R145, R150, R153, R155, R158, R160: 10K; R_1206_3216Metric
R55, R83, R115, R118, R121, R123, R126, R129, R131, R141, R144, R149, R152, R154, R157, R159: 100K; R_1206_3216Metric

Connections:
+5V: R17.2, R54.2, R55.2, R82.2, R83.2, R112.2, R113.2, R114.2, R115.2, R117.2, R118.2, R120.2, R121.2, R123.2, R125.2, R126.2, R128.2, R129.2, R131.2, R140.2, R141.2, R144.2, R146.2, R147.2, R148.2, R149.2, R151.2, R152.2, R154.2, R156.2, R157.2, R159.2; also elsewhere on the board
GND: C1.2, C2.2, C3.2, C4.2, C5.2, C6.2, C7.2, C8.2, C9.2, C10.2, C11.2, C12.2, C13.2, C14.2, C15.2, C16.2, R40.2, R65.2, R105.2, R106.2, R107.2, R108.2, R109.2, R110.2, R111.2, R133.2, R134.2, R135.2, R136.2, R137.2, R138.2, R139.2; also elsewhere on the board
InputToDev_1: R56.1; also elsewhere on the board
InputToDev_2: R84.1; also elsewhere on the board
InputToDev_3: R142.1; also elsewhere on the board
InputToDev_4: R132.1; also elsewhere on the board
InputToDev_5: R122.1; also elsewhere on the board
InputToDev_6: R145.1; also elsewhere on the board
InputToDev_7: R153.1; also elsewhere on the board
InputToDev_8: R116.1; also elsewhere on the board
InputToDev_9: R124.1; also elsewhere on the board
InputToDev_10: R119.1; also elsewhere on the board
InputToDev_11: R130.1; also elsewhere on the board
InputToDev_12: R127.1; also elsewhere on the board
InputToDev_13: R155.1; also elsewhere on the board
InputToDev_14: R150.1; also elsewhere on the board
InputToDev_15: R160.1; also elsewhere on the board
InputToDev_16: R158.1; also elsewhere on the board
InputToMC_1: C1.1, Q25.1 (C), R40.1; also elsewhere on the board
InputToMC_2: C2.1, Q34.1 (C), R65.1; also elsewhere on the board
InputToMC_3: C10.1, Q58.1 (C), R133.1; also elsewhere on the board
InputToMC_4: C9.1, Q57.1 (C), R111.1; also elsewhere on the board
InputToMC_5: C5.1, Q53.1 (C), R107.1; also elsewhere on the board
InputToMC_6: C11.1, Q59.1 (C), R134.1; also elsewhere on the board
InputToMC_7: C13.1, Q61.1 (C), R136.1; also elsewhere on the board
InputToMC_8: C3.1, Q51.1 (C), R105.1; also elsewhere on the board
InputToMC_9: C6.1, Q54.1 (C), R108.1; also elsewhere on the board
InputToMC_10: C4.1, Q52.1 (C), R106.1; also elsewhere on the board
InputToMC_11: C8.1, Q56.1 (C), R110.1; also elsewhere on the board
InputToMC_12: C7.1, Q55.1 (C), R109.1; also elsewhere on the board
InputToMC_13: C14.1, Q62.1 (C), R137.1; also elsewhere on the board
InputToMC_14: C12.1, Q60.1 (C), R135.1; also elsewhere on the board
InputToMC_15: C16.1, Q64.1 (C), R139.1; also elsewhere on the board
InputToMC_16: C15.1, Q63.1 (C), R138.1; also elsewhere on the board
unnamed: Q25.2 (B), R55.1, R56.2
unnamed: Q25.3 (E), R54.1
unnamed: Q34.2 (B), R83.1, R84.2
unnamed: Q34.3 (E), R82.1
unnamed: Q51.2 (B), R115.1, R116.2
unnamed: Q51.3 (E), R112.1
unnamed: Q52.2 (B), R118.1, R119.2
unnamed: Q52.3 (E), R113.1
unnamed: Q53.2 (B), R121.1, R122.2
unnamed: Q53.3 (E), R114.1
unnamed: Q54.2 (B), R123.1, R124.2
unnamed: Q54.3 (E), R117.1
unnamed: Q55.2 (B), R126.1, R127.2
unnamed: Q55.3 (E), R120.1
unnamed: Q56.2 (B), R129.1, R130.2
unnamed: Q56.3 (E), R125.1
unnamed: Q57.2 (B), R131.1, R132.2
unnamed: Q57.3 (E), R128.1
unnamed: Q58.2 (B), R141.1, R142.2
unnamed: Q58.3 (E), R140.1
unnamed: Q59.2 (B), R144.1, R145.2
unnamed: Q59.3 (E), R17.1
unnamed: Q60.2 (B), R149.1, R150.2
unnamed: Q60.3 (E), R146.1
unnamed: Q61.2 (B), R152.1, R153.2
unnamed: Q61.3 (E), R147.1
unnamed: Q62.2 (B), R154.1, R155.2
unnamed: Q62.3 (E), R148.1
unnamed: Q63.2 (B), R157.1, R158.2
unnamed: Q63.3 (E), R151.1
unnamed: Q64.2 (B), R159.1, R160.2
unnamed: Q64.3 (E), R156.1

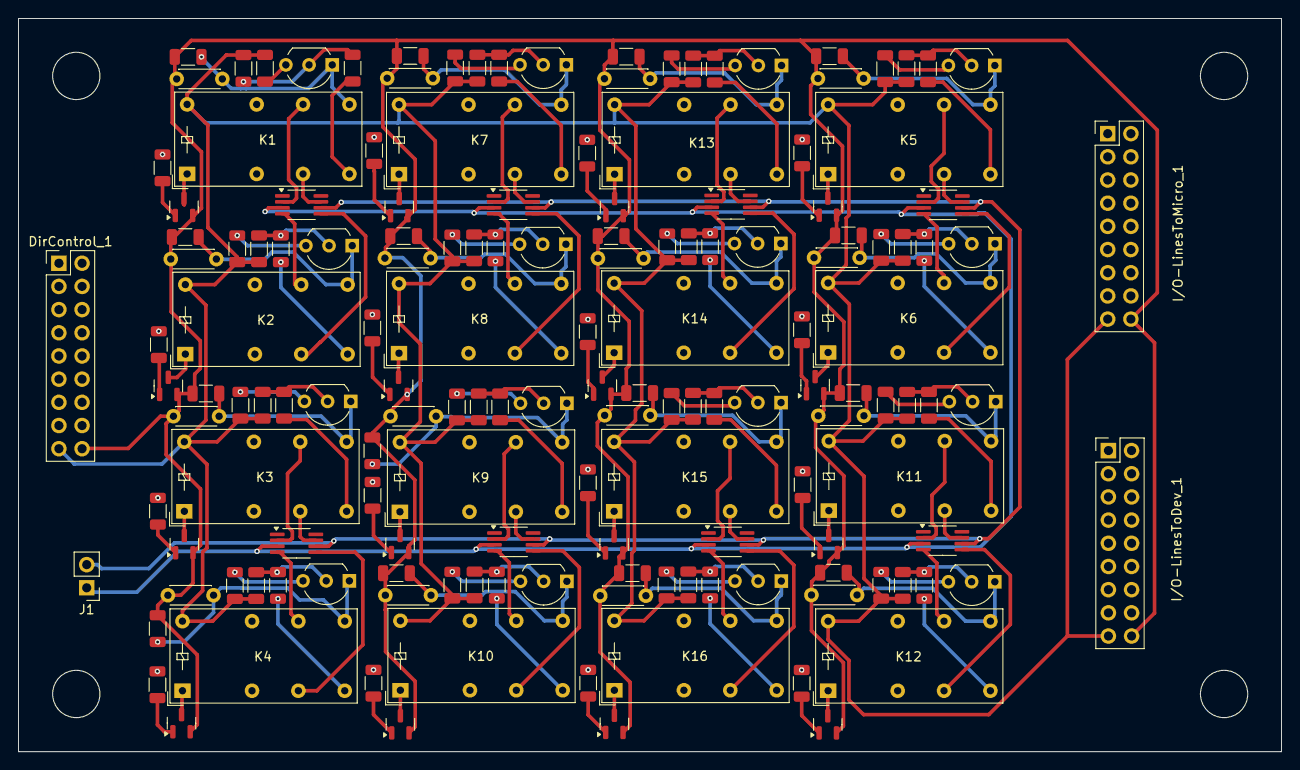
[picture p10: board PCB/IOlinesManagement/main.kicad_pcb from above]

Board: 4 copper layers, 138.4 x 80.3 mm, 156 parts (0 on the bottom side), 180 nets.

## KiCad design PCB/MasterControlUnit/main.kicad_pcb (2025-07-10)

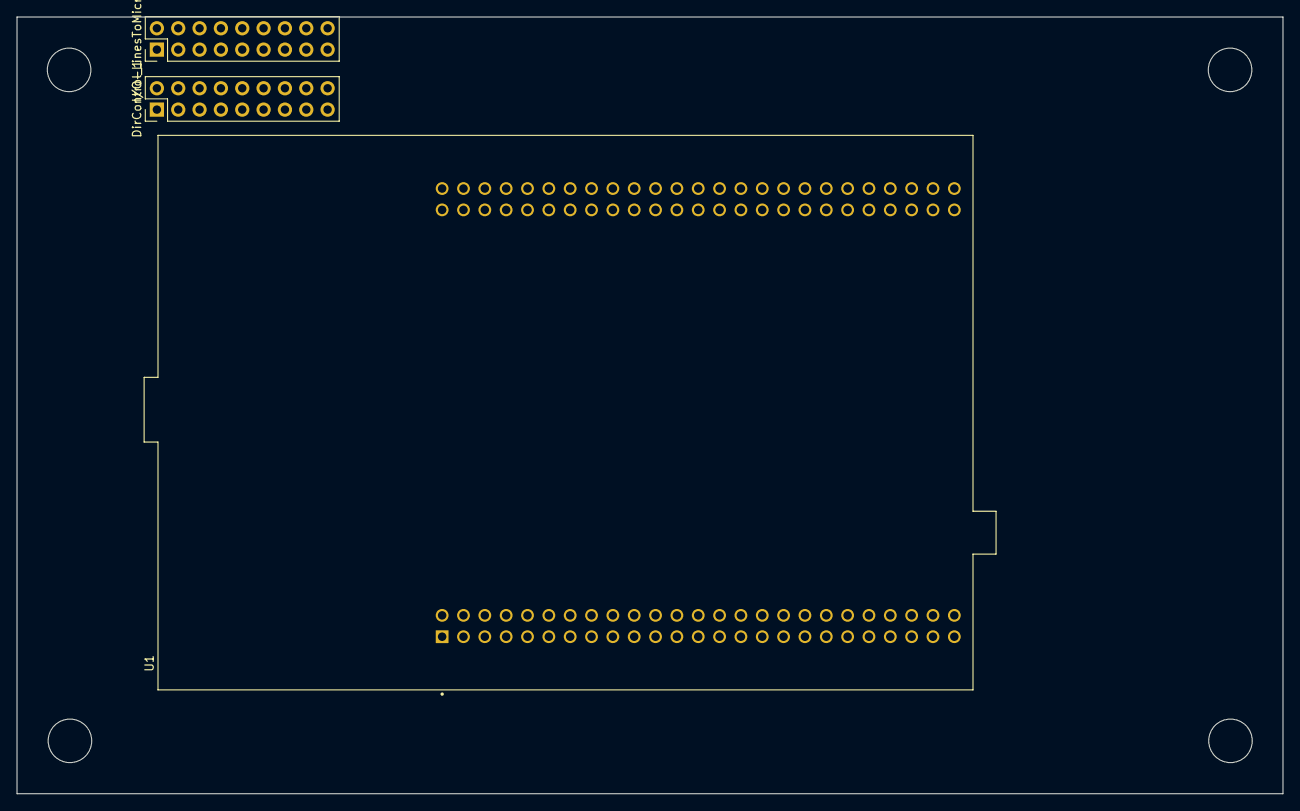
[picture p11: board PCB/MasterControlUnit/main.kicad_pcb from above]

Board: 2 copper layers, 150.7 x 92.4 mm, 3 parts (0 on the bottom side), 2 nets, no tracks yet.

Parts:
DirControl_1: Conn_02x09_Top_Bottom; PinHeader_2x09_P2.54mm_Vertical
I/O-LinesToMicro_1: Conn_02x09_Top_Bottom; PinHeader_2x09_P2.54mm_Vertical
U1: STM32F407G-DISC1; MODULE_STM32F407G-DISC1

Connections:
+5V: DirControl_1.17, I/O-LinesToMicro_1.17
GND: DirControl_1.18, I/O-LinesToMicro_1.18

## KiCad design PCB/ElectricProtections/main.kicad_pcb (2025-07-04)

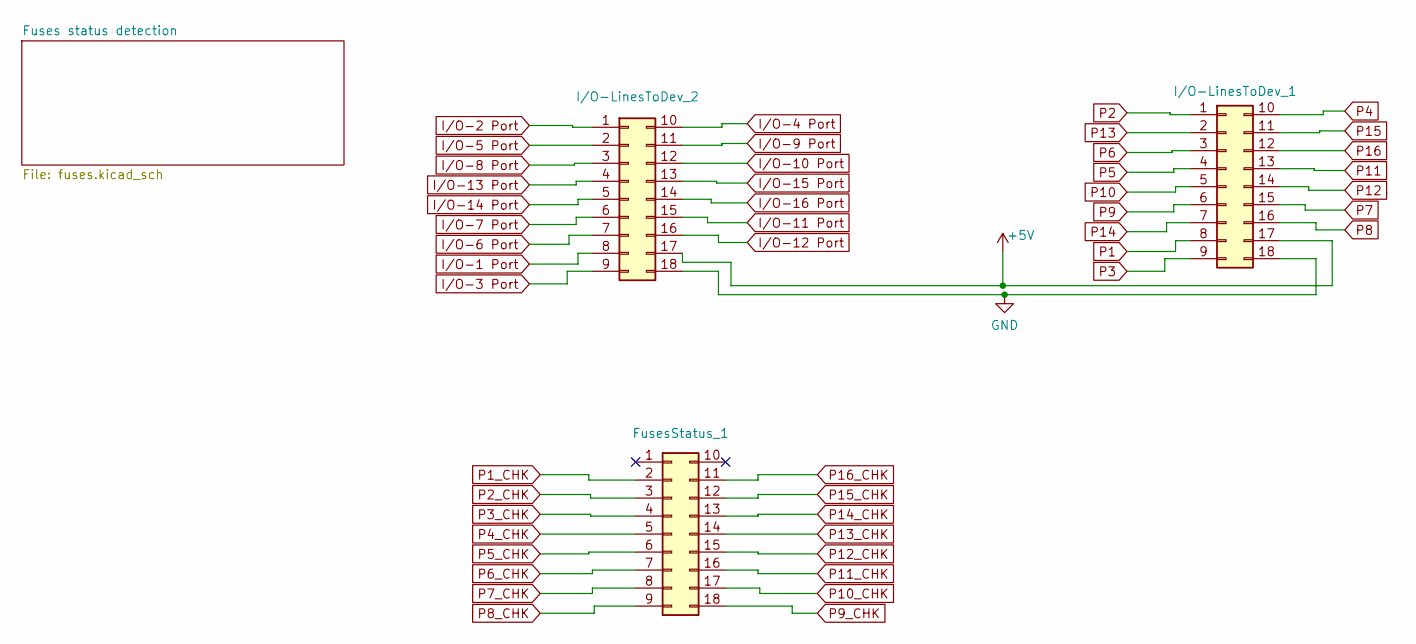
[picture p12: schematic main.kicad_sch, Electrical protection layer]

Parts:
FusesStatus_1: Conn_02x09_Top_Bottom; PinHeader_2x09_P2.54mm_Vertical
I/O-LinesToDev_1, I/O-LinesToDev_2: Conn_02x09_Top_Bottom; PinHeader_2x09_P2.54mm_Vertical

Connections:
+5V: I/O-LinesToDev_1.17, I/O-LinesToDev_2.17; also elsewhere on the board
GND: I/O-LinesToDev_1.18, I/O-LinesToDev_2.18; also elsewhere on the board
I/O-1 Port: I/O-LinesToDev_2.8; also elsewhere on the board
I/O-2 Port: I/O-LinesToDev_2.1; also elsewhere on the board
I/O-3 Port: I/O-LinesToDev_2.9; also elsewhere on the board
I/O-4 Port: I/O-LinesToDev_2.10; also elsewhere on the board
I/O-5 Port: I/O-LinesToDev_2.2; also elsewhere on the board
I/O-6 Port: I/O-LinesToDev_2.7; also elsewhere on the board
I/O-7 Port: I/O-LinesToDev_2.6; also elsewhere on the board
I/O-8 Port: I/O-LinesToDev_2.3; also elsewhere on the board
I/O-9 Port: I/O-LinesToDev_2.11; also elsewhere on the board
I/O-10 Port: I/O-LinesToDev_2.12; also elsewhere on the board
I/O-11 Port: I/O-LinesToDev_2.15; also elsewhere on the board
I/O-12 Port: I/O-LinesToDev_2.16; also elsewhere on the board
I/O-13 Port: I/O-LinesToDev_2.4; also elsewhere on the board
I/O-14 Port: I/O-LinesToDev_2.5; also elsewhere on the board
I/O-15 Port: I/O-LinesToDev_2.13; also elsewhere on the board
I/O-16 Port: I/O-LinesToDev_2.14; also elsewhere on the board
P1: I/O-LinesToDev_1.8; also elsewhere on the board
P1_CHK: FusesStatus_1.2; also elsewhere on the board
P2: I/O-LinesToDev_1.1; also elsewhere on the board
P2_CHK: FusesStatus_1.3; also elsewhere on the board
P3: I/O-LinesToDev_1.9; also elsewhere on the board
P3_CHK: FusesStatus_1.4; also elsewhere on the board
P4: I/O-LinesToDev_1.10; also elsewhere on the board
P4_CHK: FusesStatus_1.5; also elsewhere on the board
P5: I/O-LinesToDev_1.4; also elsewhere on the board
P5_CHK: FusesStatus_1.6; also elsewhere on the board
P6: I/O-LinesToDev_1.3; also elsewhere on the board
P6_CHK: FusesStatus_1.7; also elsewhere on the board
P7: I/O-LinesToDev_1.15; also elsewhere on the board
P7_CHK: FusesStatus_1.8; also elsewhere on the board
P8: I/O-LinesToDev_1.16; also elsewhere on the board
P8_CHK: FusesStatus_1.9; also elsewhere on the board
P9: I/O-LinesToDev_1.6; also elsewhere on the board
P9_CHK: FusesStatus_1.18; also elsewhere on the board
P10: I/O-LinesToDev_1.5; also elsewhere on the board
P10_CHK: FusesStatus_1.17; also elsewhere on the board
P11: I/O-LinesToDev_1.13; also elsewhere on the board
P11_CHK: FusesStatus_1.16; also elsewhere on the board
P12: I/O-LinesToDev_1.14; also elsewhere on the board
P12_CHK: FusesStatus_1.15; also elsewhere on the board
P13: I/O-LinesToDev_1.2; also elsewhere on the board
P13_CHK: FusesStatus_1.14; also elsewhere on the board
P14: I/O-LinesToDev_1.7; also elsewhere on the board
P14_CHK: FusesStatus_1.13; also elsewhere on the board
P15: I/O-LinesToDev_1.11; also elsewhere on the board
P15_CHK: FusesStatus_1.12; also elsewhere on the board
P16: I/O-LinesToDev_1.12; also elsewhere on the board
P16_CHK: FusesStatus_1.11; also elsewhere on the board

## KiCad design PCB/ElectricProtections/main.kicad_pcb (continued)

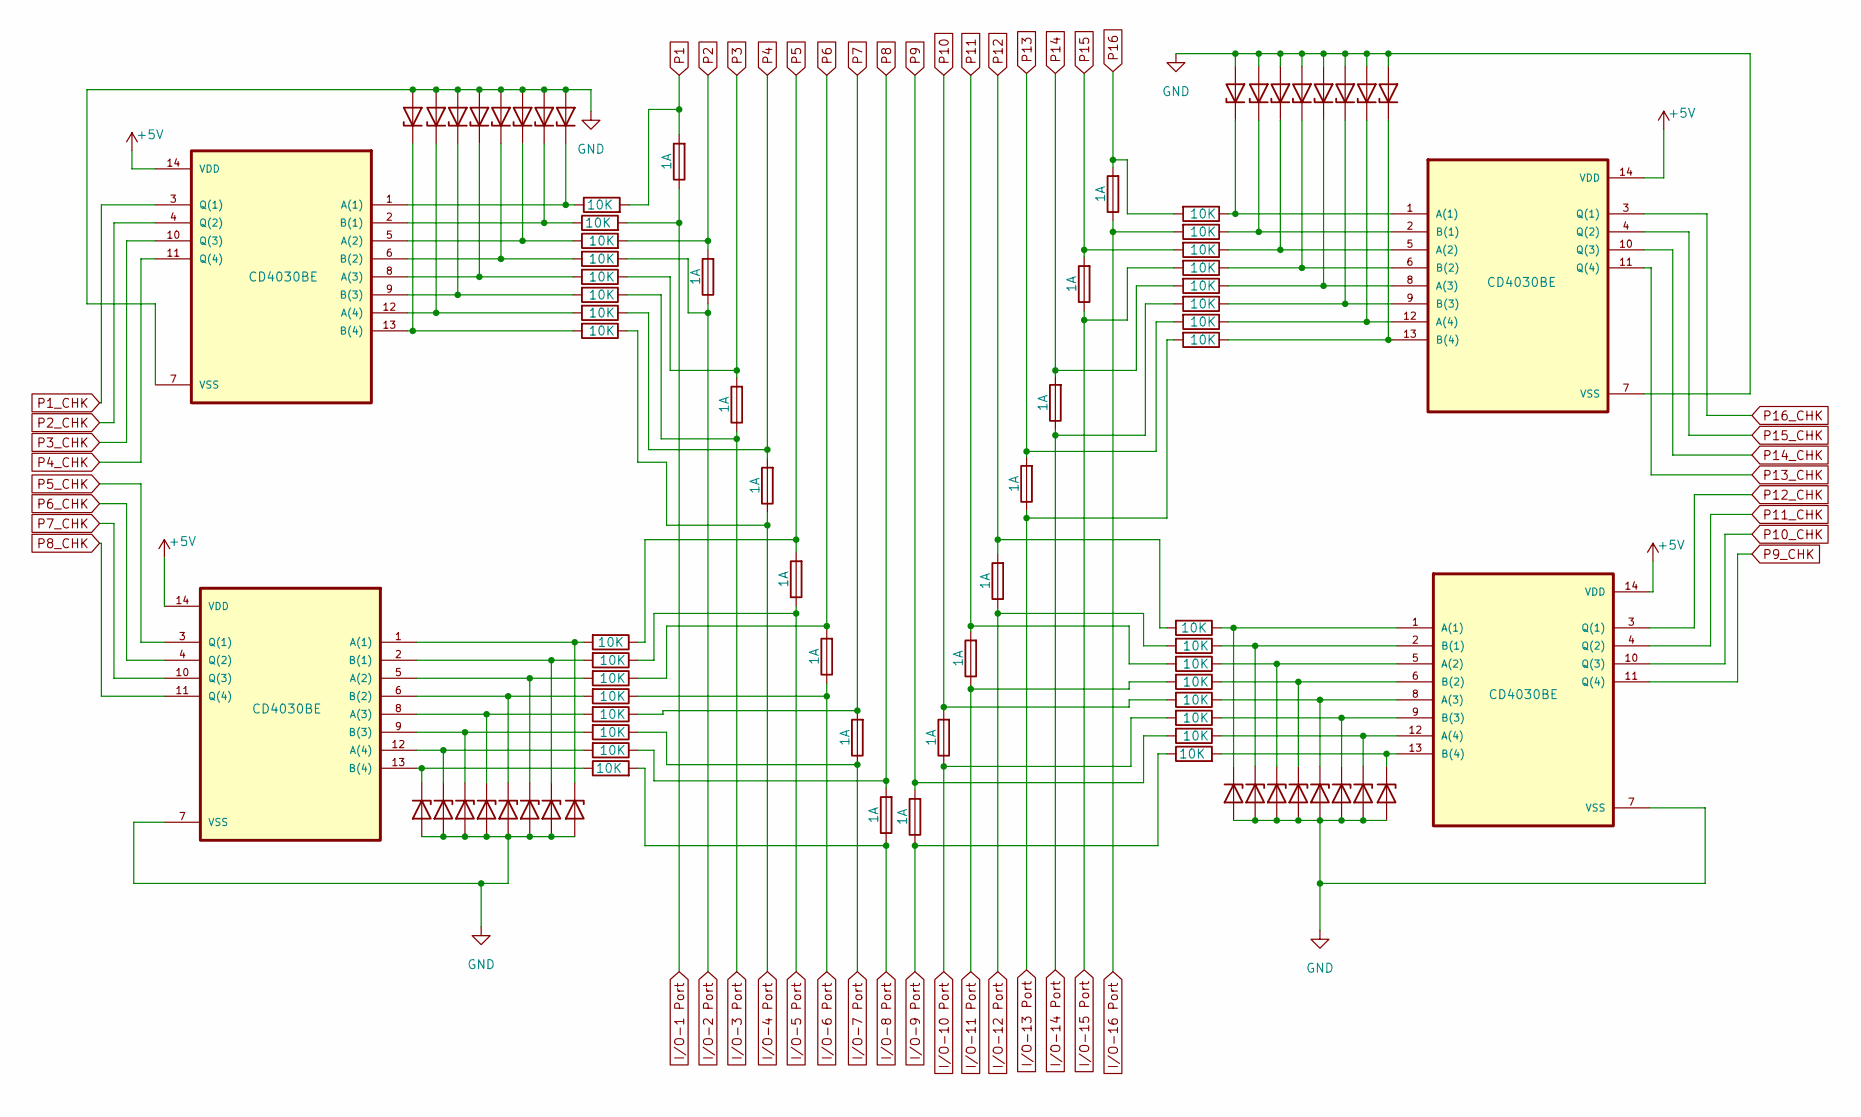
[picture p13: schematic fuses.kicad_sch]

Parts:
D1, D2, D3, D4, D5, D6, D7, D8, D9, D10, D11, D12, D13, D14, D15, D16, D17, D18, D19, D20, D21, D22, D23, D24, D25, D26, D27, D28, D29, D30, D31, D32: 5V; D_1206_3216Metric
F1, F2, F3, F4, F5, F6, F7, F8, F9, F10, F11, F12, F13, F14, F15, F16: 1A; Fuseholder_Cylinder-5x20mm_Schurter_0031_8201_Horizontal_Op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
R1, R2, R3, R4, R5, R6, R7, R8, R9, R10, R11, R12, R13, R14, R15, R16, R17, R18, R19, R20, R21, R22, R23, R24, R25, R26, R27, R28, R29, R30, R31, R32: 10K; R_1206_3216Metric
U1, U2, U3, U4: CD4030BE; DIP-14_W7.62mm_LongPads

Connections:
+5V: U1.14 (VDD), U2.14 (VDD), U3.14 (VDD), U4.14 (VDD); also elsewhere on the board
GND: D1.2 (A), D2.2 (A), D3.2 (A), D4.2 (A), D5.2 (A), D6.2 (A), D7.2 (A), D8.2 (A), D9.2 (A), D10.2 (A), D11.2 (A), D12.2 (A), D13.2 (A), D14.2 (A), D15.2 (A), D16.2 (A), D17.2 (A), D18.2 (A), D19.2 (A), D20.2 (A), D21.2 (A), D22.2 (A), D23.2 (A), D24.2 (A), D25.2 (A), D26.2 (A), D27.2 (A), D28.2 (A), D29.2 (A), D30.2 (A), D31.2 (A), D32.2 (A), U1.7 (VSS), U2.7 (VSS), U3.7 (VSS), U4.7 (VSS); also elsewhere on the board
I/O-1 Port: F1.1, R23.2; also elsewhere on the board
I/O-2 Port: F2.1, R21.1; also elsewhere on the board
I/O-3 Port: F3.1, R19.1; also elsewhere on the board
I/O-4 Port: F4.1, R17.1; also elsewhere on the board
I/O-5 Port: F5.1, R26.1; also elsewhere on the board
I/O-6 Port: F6.1, R28.1; also elsewhere on the board
I/O-7 Port: F7.1, R30.1; also elsewhere on the board
I/O-8 Port: F8.1, R32.2; also elsewhere on the board
I/O-9 Port: F9.1, R16.1; also elsewhere on the board
I/O-10 Port: F10.1, R14.2; also elsewhere on the board
I/O-11 Port: F11.1, R12.2; also elsewhere on the board
I/O-12 Port: F12.1, R10.2; also elsewhere on the board
I/O-13 Port: F13.1, R8.2; also elsewhere on the board
I/O-14 Port: F14.1, R6.2; also elsewhere on the board
I/O-15 Port: F15.1, R2.2; also elsewhere on the board
I/O-16 Port: F16.1, R4.2; also elsewhere on the board
unnamed: D1.1 (K), R23.1, U1.2 (B(1))
unnamed: D2.1 (K), R24.1, U1.5 (A(2))
unnamed: D3.1 (K), R21.2, U1.6 (B(2))
unnamed: D4.1 (K), R20.2, U1.8 (A(3))
unnamed: D5.1 (K), R19.2, U1.9 (B(3))
unnamed: D6.1 (K), R18.2, U1.12 (A(4))
unnamed: D7.1 (K), R17.2, U1.13 (B(4))
unnamed: D8.1 (K), R22.1, U1.1 (A(1))
unnamed: D9.1 (K), R1.1, U4.1 (A(1))
unnamed: D10.1 (K), R4.1, U4.2 (B(1))
unnamed: D11.1 (K), R3.1, U4.5 (A(2))
unnamed: D12.1 (K), R2.1, U4.6 (B(2))
unnamed: D13.1 (K), R7.1, U4.8 (A(3))
unnamed: D14.1 (K), R6.1, U4.9 (B(3))
unnamed: D15.1 (K), R5.1, U4.12 (A(4))
unnamed: D16.1 (K), R8.1, U4.13 (B(4))
unnamed: D17.1 (K), R16.2, U3.13 (B(4))
unnamed: D18.1 (K), R15.1, U3.12 (A(4))
unnamed: D19.1 (K), R14.1, U3.9 (B(3))
unnamed: D20.1 (K), R13.1, U3.8 (A(3))
unnamed: D21.1 (K), R12.1, U3.6 (B(2))
unnamed: D22.1 (K), R11.1, U3.5 (A(2))
unnamed: D23.1 (K), R10.1, U3.2 (B(1))
unnamed: D24.1 (K), R9.1, U3.1 (A(1))
unnamed: D25.1 (K), R32.1, U2.13 (B(4))
unnamed: D26.1 (K), R31.2, U2.12 (A(4))
unnamed: D27.1 (K), R30.2, U2.9 (B(3))
unnamed: D28.1 (K), R29.2, U2.8 (A(3))
unnamed: D29.1 (K), R28.2, U2.6 (B(2))
unnamed: D30.1 (K), R27.2, U2.5 (A(2))
unnamed: D31.1 (K), R26.2, U2.2 (B(1))
unnamed: D32.1 (K), R25.2, U2.1 (A(1))
P1: F1.2, R22.2; also elsewhere on the board
P1_CHK: U1.3 (Q(1)); also elsewhere on the board
P2: F2.2, R24.2; also elsewhere on the board
P2_CHK: U1.4 (Q(2)); also elsewhere on the board
P3: F3.2, R20.1; also elsewhere on the board
P3_CHK: U1.10 (Q(3)); also elsewhere on the board
P4: F4.2, R18.1; also elsewhere on the board
P4_CHK: U1.11 (Q(4)); also elsewhere on the board
P5: F5.2, R25.1; also elsewhere on the board
P5_CHK: U2.3 (Q(1)); also elsewhere on the board
P6: F6.2, R27.1; also elsewhere on the board
P6_CHK: U2.4 (Q(2)); also elsewhere on the board
P7: F7.2, R29.1; also elsewhere on the board
P7_CHK: U2.10 (Q(3)); also elsewhere on the board
P8: F8.2, R31.1; also elsewhere on the board
P8_CHK: U2.11 (Q(4)); also elsewhere on the board
P9: F9.2, R15.2; also elsewhere on the board
P9_CHK: U3.11 (Q(4)); also elsewhere on the board
P10: F10.2, R13.2; also elsewhere on the board
P10_CHK: U3.10 (Q(3)); also elsewhere on the board
P11: F11.2, R11.2; also elsewhere on the board
P11_CHK: U3.4 (Q(2)); also elsewhere on the board
P12: F12.2, R9.2; also elsewhere on the board
P12_CHK: U3.3 (Q(1)); also elsewhere on the board
P13: F13.2, R5.2; also elsewhere on the board
P13_CHK: U4.11 (Q(4)); also elsewhere on the board
P14: F14.2, R7.2; also elsewhere on the board
P14_CHK: U4.10 (Q(3)); also elsewhere on the board
P15: F15.2, R3.2; also elsewhere on the board
P15_CHK: U4.4 (Q(2)); also elsewhere on the board
P16: F16.2, R1.2; also elsewhere on the board
P16_CHK: U4.3 (Q(1)); also elsewhere on the board

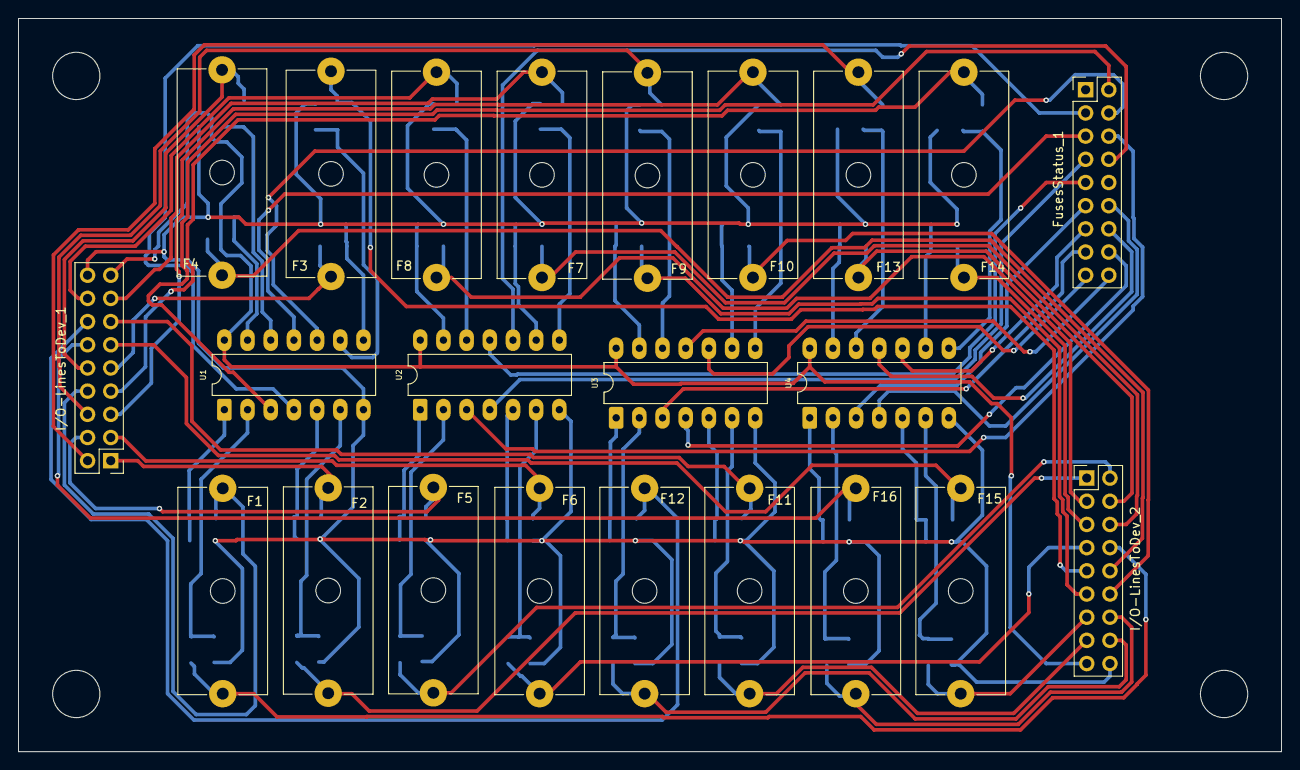
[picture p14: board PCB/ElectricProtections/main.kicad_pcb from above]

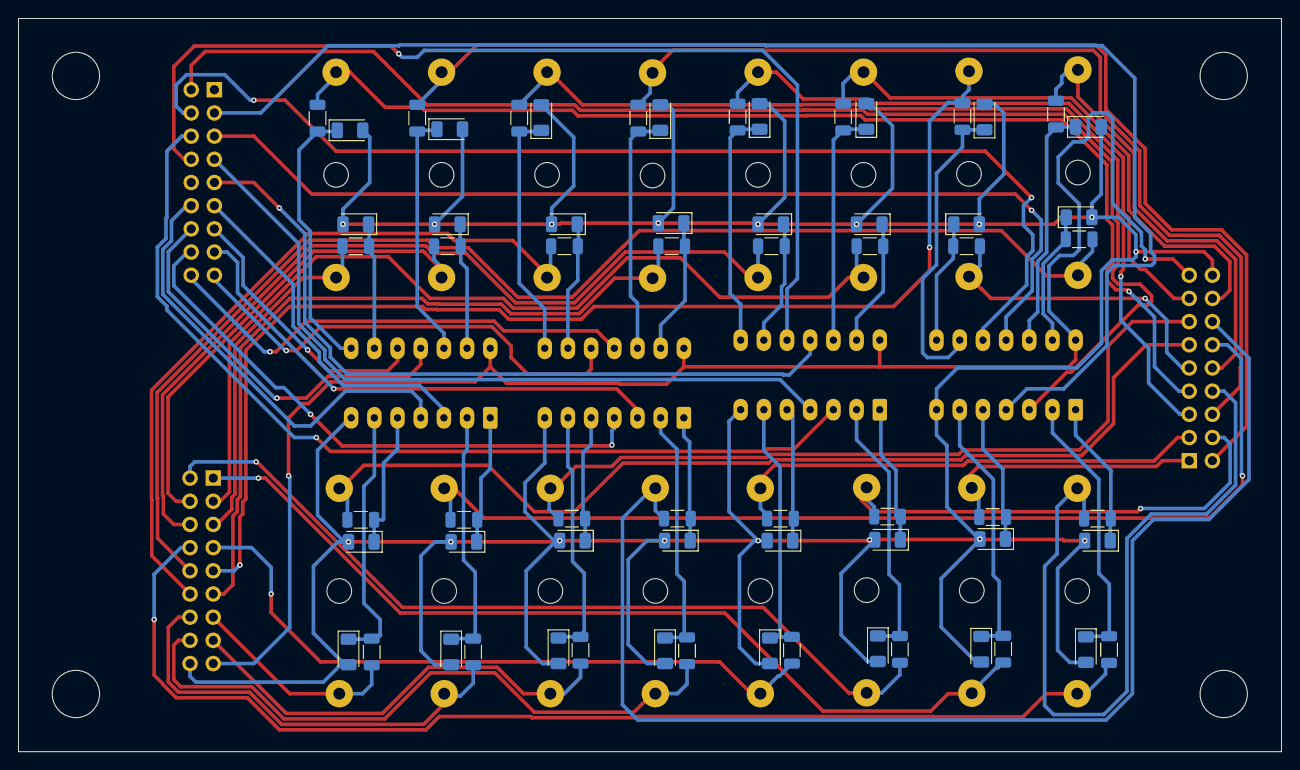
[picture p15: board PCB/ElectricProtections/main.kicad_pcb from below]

Board: 2 copper layers, 138.4 x 80.3 mm, 87 parts (64 on the bottom side), 82 nets.

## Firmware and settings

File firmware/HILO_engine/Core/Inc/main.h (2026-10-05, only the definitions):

#define VCP_TX_Pin       GPIO_PIN_2
#define VCP_TX_GPIO_Port GPIOA
#define SWDIO_Pin        GPIO_PIN_13
#define SWDIO_GPIO_Port  GPIOA
#define SWCLK_Pin        GPIO_PIN_14
#define SWCLK_GPIO_Port  GPIOA
#define VCP_RX_Pin       GPIO_PIN_15
#define VCP_RX_GPIO_Port GPIOA
#define OUTCONF_STORAGE_SIZE (16 * 1024 * 1024)
#define HENG_TEST_START     8
#define HENG_TEST_STOP      10
#define HENG_TEST_GETSTATUS 12
#define HENG_TEST_ITCONF   18
#define HENG_TEST_ITCONF   20
#define HENG_SUCCESS             1
#define HENG_WARNING_NOTHINGTODO 34
#define HENG_ERROR_ILLEGALCMD    130
#define HENG_ERROR_CONIGMISSING  132

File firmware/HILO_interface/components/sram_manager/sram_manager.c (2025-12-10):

/*------------------------------------------------------------------------------------------------------------------------------
//                                                    _   _ ___ _     ___  
//                                                   | | | |_ _| |   / _ \
//                                                   | |_| || || |  | | | |
//                                                   |  _  || || |__| |_| |
//                                                   |_| |_|___|_____\___/ 
//                                                    Hardware in the loop
//
//
// File:   sram_manager.c
//
// Author: Silvano Catinella <catinella@yahoo.com>
//
// Description:
//		This library provides useful features for the APS6404L-3SQR-SN 8Mbytes SRAM management
//		In order to minimize the used time, the read/write operations are always implemented sequentially, except of the
//		first	record. In fact that record is used to keep track of the stored-items number and it will be updated just at
//		the end.
//
//		Internal data reppresentation:
//		==============================
//		Every record has 64bit size
//		0                                              64MB
//		+---------------+------------------------------+
//		| Num. of items | item1 | item2 |//////////////| 
//		+---------------+-------+-------+--------------+
//
//		Multiple SRAMs access
//		=====================
//		In order to get the advantages of the SRAM solution, it has been needed to use more devices to achieve 64MB size.
//		In fact the APS6404L-3SQR-SN maximum size is just 8MB and bigger SRAM devices cannot be welded by humans!! :-O
//		64MB looks like a huge quantity of memory, but considering every round HILO would save 8 bytes for round and it
//		would be do it 100 000 times per second (at maximum speed). It means the test must be shorter then (64MB/800KB)
//		80 seconds.
//		At the beginning the idea was to store data using a round-robin access to all chips. But, in this solution every
//		one of them require to get the new (24bit) address for every writing operations. It makes the the operation too
//		slow!!!
//		In the new solution data is written in the firts chip unless it is full, then the new data will be written in the
//		next until also this chip will be full, and so on....
//		
//
// License:  LGPL ver 3.0
//
// 		This script is a free software; you can redistribute it and/or modify it under the terms	of the GNU
// 		Lesser General Public License as published by the Free Software Foundation; either version 3.0 of the License,
// 		or (at your option) any later version. 
//
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
//			Free Software Foundation, Inc.,
//			59 Temple Place, Suite 330,
//			Boston, MA  02111-1307  USA
//
//
------------------------------------------------------------------------------------------------------------------------------*/
//
// Common C libraries
//
#include <stdio.h>
#include <stdbool.h>

#ifdef MOCK
//
// Libraries used for testing purpose
//
#include "./test/mockedFunctions.h"

#else
//
// ESP32 platform dependent libraries
//
#include "driver/spi_master.h"
#endif

// Other libraries
#include <sram_manager.h>


#if __BYTE_ORDER__ == __ORDER_LITTLE_ENDIAN__
#define LITTLE_ENDIAN
#undef  BIG_ENDIAN

#elif __BYTE_ORDER__ == __ORDER_BIG_ENDIAN__
#undef  LITTLE_ENDIAN
#define BIG_ENDIAN
#endif

typedef enum {
	SRAMMAN_OP_RESET,
	SRAMMAN_OP_READ,
	SRAMMAN_OP_WRITE
} sramRwOpsType;


#define SRAM_CHIPSIZE (SRAMMAN_MAXSIZE / SRAMMAN_NUMOFBANKS)


//
// Module's variables
//
static spi_device_handle_t sram_devsHandles[SRAMMAN_NUMOFBANKS]; // Handle of every SRAM chip
static uint32_t            sram_noi        = 0;                  // Number Of (written) Items


//------------------------------------------------------------------------------------------------------------------------------
//                                       P R I V A T E   F U N C T I O N S
//------------------------------------------------------------------------------------------------------------------------------
#ifndef MOCK
static wError _spi_initialization();
#endif
static void   _recordToArray     (ssRecord src, uint8_t *arr);
static wError _sram_seqOP        (spi_device_handle_t dev, uint16_t addr, ssRecord *data, bool flag, sramRwOpsType opt);
static wError _sram_mcSeqOP      (uint64_t *record, sramRwOpsType opt);


#ifndef MOCK
wError _spi_initialization() {
	//
	// Description:
	//	It initializes the SPI port used by the SRAM devices to communicate to the ESP32
	//
	// Returned value
	//	WERROR_SUCCESS
	//	WERROR_ERROR_SPIBUSERROR
	//
	wError                        err = WERROR_SUCCESS;
	spi_bus_config_t              buscfg = {};
	spi_device_interface_config_t devcfg = {};
	esp_err_t                     espErr;
	
	buscfg.mosi_io_num     = SRAMMAN_ESP32PIN_MOSI;
	buscfg.miso_io_num     = SRAMMAN_ESP32PIN_MISO;
	buscfg.sclk_io_num     = SRAMMAN_ESP32PIN_CLK;
	buscfg.quadwp_io_num   = -1;
	buscfg.quadhd_io_num   = -1;
	buscfg.max_transfer_sz = 4096;

	devcfg.clock_speed_hz  = SRAMMAN_ESP32SPI_CLK;
	devcfg.mode            = 0;                           // CPOL=0, CPHA=0
	devcfg.queue_size      = 4;

	// SPI BUS initialization
	if (spi_bus_initialize(SPI1_HOST, &buscfg, SPI_DMA_CH_AUTO) == ESP_OK) {

		// SRAM devices adding
		uint8_t csPinsList[SRAMMAN_NUMOFBANKS] = SRAMMAN_CSPINSLIST ;

		for (uint8_t t = 0; t < SRAMMAN_NUMOFBANKS; t++) {
			devcfg.spics_io_num = csPinsList[t];
			espErr = spi_bus_add_device(SPI1_HOST, &devcfg, (sram_devsHandles + t));
			if (espErr != ESP_OK) {
				// ERROR!
				// TODO: errorlog
				err = WERROR_ERROR_SPIBUSERROR;
				break;
			}
		}
	} else {
		// ERROR!
		// TODO: errorlog
		err = WERROR_ERROR_SPIBUSERROR;
	}
	return(err);
}
#endif


void _recordToArray (ssRecord src, uint8_t *arr) {
	//
	// Description:
	//	In order to send/receive data to/from the SRAM using DMA the ssRecord data must be splitted in bytes array
	//	[!] Most of CPUs and MCUs use little endian convention
	//
	for (uint8_t t = 0; t < sizeof(ssRecord); t++)
#ifdef LITTLE_ENDIAN
		arr[t] = (uint8_t)((src >> (t*8)) & 0xFF);
#else
		arr[7 - t] = (uint8_t)((src >> (t*8)) & 0xFF);
#endif
	return;
}
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

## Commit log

2025-06-18 Change: push-pull output configuration
    [IO_0116.kicad_sch]
2025-06-18 Duplicated components names fixed
    [IO_0116.kicad_sch, dirController_0116.kicad_sch, main.kicad_sch]
2025-06-19 Fingerprints assignment
    [IO_0116.kicad_sch, dirController_0116.kicad_sch, main.kicad_sch]
2025-06-19 Component size reduction and fixes
    - Some connection to GND has been fixed
    - The biggest part of (THT) BC337 components has been replaced by (SMD) BC817
    [IO_0116.kicad_sch, dirController_0116.kicad_sch]
2025-06-20 DIRColtrol_1 pins assignment changed
    [main.kicad_sch]
2025-06-20 Uncomplited version
    Sorry, it is just for backup
    [main.kicad_pcb]
2025-06-24 Changes: balanced push-pull architecture
    At the beginning the idea was to allow the user to generate digital outputs with different formats.. (5, 12V..). In order
    to achieve the result I used a customized push-pull structure with three NPN transistors. But that solution wastes a bit of
    current and it not a good one, at the end. So, I have changed to a more common push-pull (PNP + NPN), but the output is not
    connected to the transistors emitter, but to their collector, so the transistors work always on saturation area.
    [IO_0116.kicad_sch]
2025-06-24 99% completed release
    [main.kicad_pcb]
2025-06-25 First completed release
    In order to avoid the size explosion, I have been forced to use a multilayer PCB.
    It increases the building prices, I know it.
    [main.kicad_pcb]
2025-06-25 Connector pins adjustment
    [main.kicad_sch]
2025-06-25 Small size reduction ans fixes
    [main.kicad_pcb]
2025-06-26 Change: the output interfaces have been moved to another file
    [IO_0116.kicad_sch, inputs_0116.kicad_sch]
2025-06-26 Change: new push-pull scheme
    [outputs_0116.kicad_sch]
2025-06-26 Fixes and updates
    [inputs_0116.kicad_sch, main.kicad_sch]
2025-06-30 Electric protection layer for output lines
    [fuses.kicad_sch, main.kicad_sch]
2025-06-30 Enhancement: push-pull components-blocks have been replaced by MIC4427 devices
    We are not more living in the 1990 age :-(
    [outputs_0116.kicad_sch]
2025-07-02 Connectors pins-map has been changed
    [main.kicad_sch]
2025-07-02 New version based on MIC4427 push-pull driver
    [main.kicad_pcb]
2025-07-02 Small fix
    [main.kicad_pcb]
2025-07-03 Fuses management PCB is now completed ;-)
    [main.kicad_pcb]
2025-07-04 Small size reduction
    [main.kicad_pcb]
2025-07-04 Updates and small enhancements
    - PCB size updating
    - More space (1.4mm) between the fuses
    [main.kicad_pcb]
2025-07-10 KiCAD symbols and footprint added
    STM32F407G-DISC1 device's symbol and footprint
    These files have been kindly provided by the https://www.snapeda.com website
2025-07-10 The HILO's brain PCB (uncompleted version)
    [main.kicad_pcb, main.kicad_sch]
2025-09-04 Fixes and updates
    - _sram_seqWrite(): it has been converted in the more generic _sram_seqOP()
    - _sram_seqRWops(): it has been renamed to _sram_mcSeqOP()
    - _sram_mcSeqOP(): updates
    - sramManager_write(): updates
    [sram_manager.c]
2025-09-05 Fixes and unit test support added
    [sram_manager.c]
2025-09-07 Fixes and refactoring
    The platform dependent calls have been mocked in a proper module.
    [sram_manager.c, sram_manager.h]
2025-09-10 Small change
    Current-dir has been added to the include-paths list
2025-09-10 Fixes for test_initialization() and spi_device_polling_transmit()
    [sram_manager__mockedFunctions.c]
2025-09-10 testEnd() prototype added
2025-09-10 Fix for _sram_seqOP()
    - command setting missing
    [sram_manager.c]
2025-09-11 Fix for spi_device_polling_transmit()
    - Wrong conditional statement
    [mockedFunctions.c]
2025-09-11 Updates
    Wrong finctions' names have been fixed
    [sram_manager.h]
2025-09-11 Many fixes and changes
    _sram_seqOP()
    The address arg is no more expressed in bytes, but in the item position (1 means first, 2 means second...)
    _sram_mcSeqOP()
    Wrong NOI field overwriting fixed
    sramManager_write()
    code segmentation removed. _spi_initialization() function has been mocked
    sramManager_resetNOIfield()
    Wrong conditional statement fixed
    sramManager_updateNOIfield()
    Broken responsability chain fixed
    [sram_manager.c]
2025-09-11 Error codes symbols have been added for test environment
    - WERROR_ERRUTEST_TESTFAILED
    - WERROR_ERRUTEST_CORRUPTDATA
    [wError.h]
2025-09-11 Fix for _sram_mcSeqOP(): segmentation fault for illegal ID
    [sram_manager.c]
2025-09-15 CMakeLists.conf and main/firmware-esp32.c added
2025-09-15 wifi_intAPstart() prototype added
2025-09-17 Update for restApiServer_configure() prototype
2025-09-26 Preliminary version
    At the moment I have not yet bought the right dev-kit, so I am doing some test with an ARM cortex-M0 MCU.
    However, I wrote a Makefile for the firmware building that function very well.
    (special thanks to Chat-GPT for the support on the conversion from STM building chain to Makefile)
2025-10-21 New JSON messages for the test-configuration Rest-API
    The original idea was to allow the test-client to send all bits-configurations trought the Rest-API. But it is not a good idea,
    because the ESP32 has no enough memory to store temporary those data.
    So, the new idea is to send the test data in higher level description JSON-messages and to let the ESP32 to convert the smaller
    data version in the bits-sequences. In this way ESP32 doesn't need to store data in its internal RAM.
2025-10-25 sram_manager module has been disabled
    sram_manager module manage the SRAMs pool as a big single fast fifo. In the previouse architecture the test-client software
    proveide test-data in raw way (bit per bit) ready to be used by the HILO_engine's MCU. But, because the HILO_interface's MCU
    (ESP32) has not enough memory to store all (MBytes) data, the new solution is to provide just data-set definition, and let
    the MCU to generate the raw data. For this reason the sram_manager module is no more useful :-(
    I hope to port this module to the HILO-engine (STM32-M4) architecture.
2025-12-10 Single pin widget
2025-12-10 Licence document link/position fixed
    [mockedFunctions.h, sram_manager.h]
2025-12-15 Fixes and updates
    - registerTerminal() prototye change: connection items are only PinWidgets
    - Fix registerTerminal(): Wrong signal-to-slot connection (tanks to ChatGPT) :-)
    - Updates for clearConnections() to use pinConnection class.
    - eventFilter() has been disabled, temporaly
    - paintEvent() has been updated to use the new pinConnection class
    - delConnection() added
    - onTerminalRightClicked() slot has been updated to pinConnection class using
2025-12-16 Value changing propagation missing fixed
    - onTerminalValueChanged() slot added
    - changes for registerTerminal(): PinWidget::valueChanged signal registration
2025-12-16 onTerminalValueChanged() slot prototype added
2025-12-17 Enhancement: every pin must be set as DUT's side or Tool's side one
    - m_side property added as private one
    - getSide() method added
2025-12-17 Unwanted connection between pin of the same side, has been fixed
    - changes for pinConnection::addItem() method
2025-12-18 Fix for onTerminalValueChanged() slot
    - Fix to prevent endless signals loop
2025-12-19 Multiple connection bug has been fixed!!
    - m_linksPool() added. It allows you to find the item with a predefined characters-id without consitering the selectedItem
    - Fixes for onTerminalRightClicked() slot
    - Fixes for paintEvent() method
2025-12-27 ConnectionOverlay::paintNow() added
    It allows TestWidget to re-paint all pin connections after the PinStripe movement
2025-12-27 Enhancement for the Object constructor
    - in the dragging signal handler, a new feature has been added: the pin connections re-drawing call after the PinStripe movement
2026-02-04 Small fix: unused lost resistor removed
    [inputs_0116.kicad_sch, main.kicad_pcb]
2026-09-18 Fix for overview diagram: fuses status evaluation missing
2026-09-24 Changes and fixes for ringBuffer module
    Because the buffer's content is read from (or witten to) SRAM by DMA, the memory area must be statically fixed. For this reason,
    the processed storage part max size MUST be the 50% of the whole storage size. In this way the DMA will read/write the half part
    starting from O or from storage-size/2
2026-10-14 Updates for overview scheme
    The MCU must be able to set the HILO's I/O lines direction. But it would require further 16 GPIO! too many.
    For this reason those lines will be managed by a MCP23017 16bits bus extender (connected with I2C bus).
2026-10-14 structuring of the electrical schematic
2026-10-14 Under development
    STM32's SPI and I2C buses have been connected
2026-10-15 Under development ver
    inputDataStorage.kicad_sch will be renamed to dataStorages.kicad_sch
2026-10-15 APS6404L-3SQR-SN component symbol/footprint added
2026-10-19 inputDataStorage.kicad_sch -> testDataStorage.kicad_sch
    The cicuit of all SRAM (for bits-configurations or test's results) is defined un the testDataStorage.kicad_sch file
2026-10-20 Number of files reduction
    outputDataStorage.kicad_sch has been included in testDataStorage.kicad_sch
2026-10-20 Backup version
    before to remove the SPI dedicated to the interative mode communication. In these modality the SPI is used by the STM32 to send
    data stream the ESP32. Unfortunately the ESP32 can use just two SPI external ports
2026-10-20 Important achitectural change (or fix)
    Because ESP32 provides just two SPI ports, the original idea to use a dedicated SPI from STM32 to ESP32 cannot be implemented.
    That SPI port was meant to be used in the interactive mode to send data from the STM32 to the ESP32.
    The new idea is to use the SPI bus used to read/write the 64MB SRAM. The two MCU already shared that bus
2026-10-20 ESP32 DevKitC-V4 pinout documentation added
2026-10-21 STM32F407G-DISC1 aND 74HC138 symbols and footprints added
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2026-10-21 Espressif's repo set to legacy kicad-7 branch
2026-10-21 ADA4096-2ARMZ symbol and foot print added
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2026-10-22 ISRAM SPI not connected to the engine fixed
2026-10-27 Wrong label and unconnected pin fixed
2026-10-27 Add PSRAM decoupling capacitors, improve grounding and refine PCB routing
2026-10-28 Wrong electric power connection fixed
2026-10-28 Finalize HILO PCB routing and power distribution
    Increase 3.3V and 5V trace widths to 0.5 mm.
    Improve connector clearances and mechanical placement.
    Verify ground plane continuity and PCB design rules.
2026-10-28 Fixes for HILO's PCB sheme
    Electrolitic capacitors added for 3.3V and 5V electric power stability
